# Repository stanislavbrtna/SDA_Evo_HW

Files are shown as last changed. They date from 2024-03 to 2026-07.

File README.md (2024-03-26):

# SDA Evo Hardware Sources
Evo is a second iteration of the SDA design, it improves the SDA Wonder while using a similar form-factor. Shematics will be mostly shared with the SDA Trié.
In the pcb directory are KiCad project files for the boards used in the SDA. In the case Directory there are FreeCAD files for the SDA case.
You can find more info about the SDA Project on its [project page](https://hackaday.io/project/35165-sda-the-best-new-pda) on hackaday.io.

This design is work-in-progress.

## Known Bugs
Design is not yet verified.

## Case notes

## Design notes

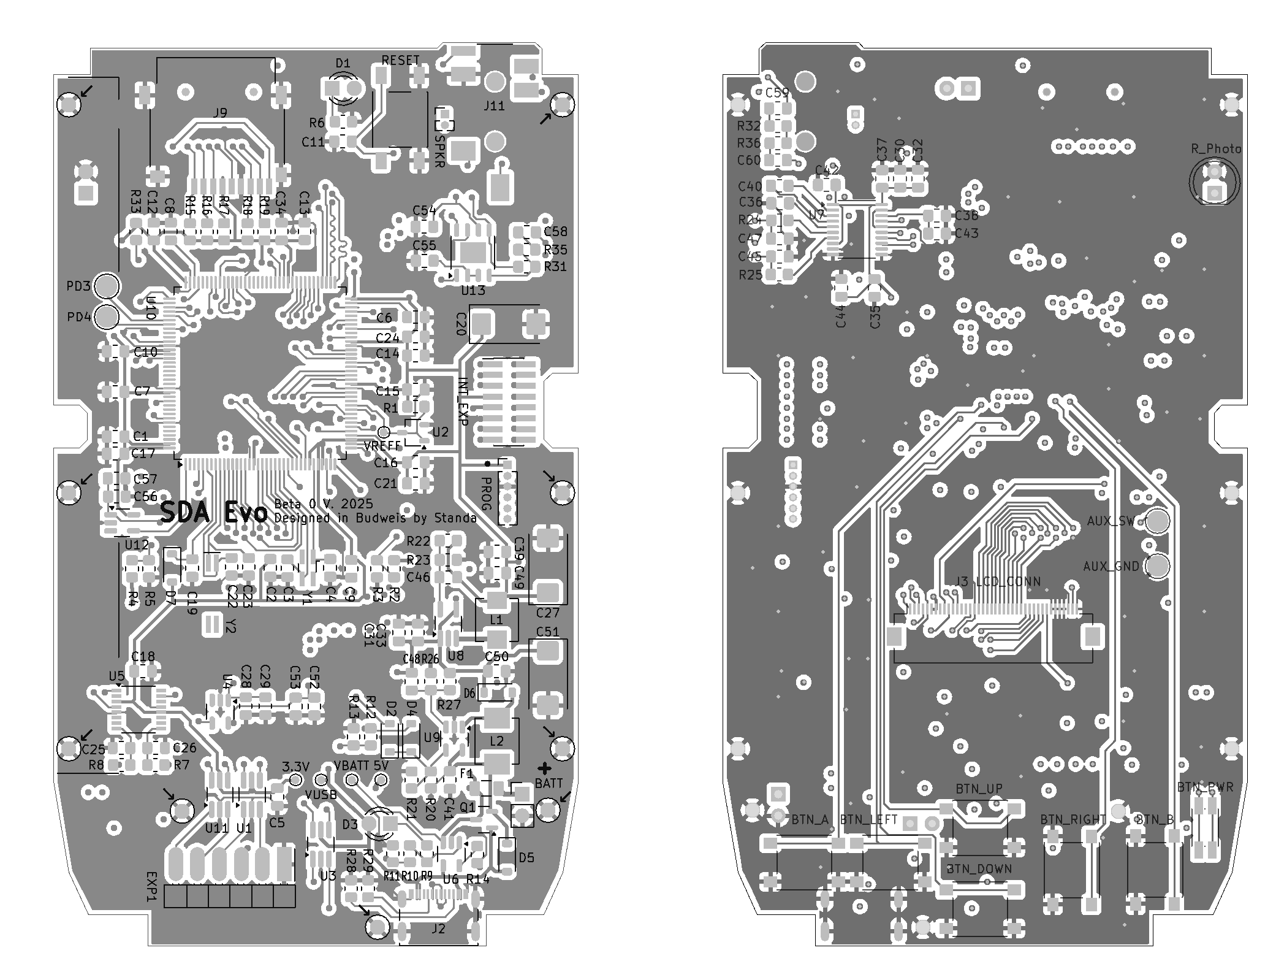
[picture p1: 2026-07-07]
Docs/Beta0/layouts.png

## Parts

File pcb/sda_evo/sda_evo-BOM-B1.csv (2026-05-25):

Reference | Value | Datasheet | Footprint | Qty | DNP
C1,C2,C5,C7,C9,C10,C11,C12,C13,C14,C15,C16,C17,C18,C28,C32,C34,C37,C43,C44,C46,C52,C54,C56 | 100n | ~ | Capacitor_SMD:C_0805_2012Metric_Pad1.18x1.45mm_HandSolder | 24
C3,C4,C22,C23 | 15p | ~ | Capacitor_SMD:C_0805_2012Metric_Pad1.18x1.45mm_HandSolder | 4
C6,C8,C19,C29,C36,C41,C57 | 2.2u | ~ | Capacitor_SMD:C_0805_2012Metric_Pad1.18x1.45mm_HandSolder | 7
C20,C27,C33,C49,C51 | 47u | ~ | Capacitor_SMD:C_0805_2012Metric_Pad1.18x1.45mm_HandSolder,Capacitor_Tantalum_SMD:CP_EIA-7343-15_Kemet-W_Pad2.25x2.55mm_HandSolder | 5
C21,C31,C39,C50,C53 | 4.7u | ~ | Capacitor_SMD:C_0805_2012Metric_Pad1.18x1.45mm_HandSolder | 5
C24,C30,C35,C38,C42 | 10u | ~ | Capacitor_SMD:C_0805_2012Metric_Pad1.18x1.45mm_HandSolder | 5
C25,C26 | 47p | ~ | Capacitor_SMD:C_0805_2012Metric_Pad1.18x1.45mm_HandSolder | 2
C40 | 22u | ~ | Capacitor_SMD:C_0805_2012Metric_Pad1.18x1.45mm_HandSolder | 1
C45,C47 | 2.2n | ~ | Capacitor_SMD:C_0805_2012Metric_Pad1.18x1.45mm_HandSolder | 2
C48 | 680p | ~ | Capacitor_SMD:C_0805_2012Metric_Pad1.18x1.45mm_HandSolder | 1
C55 | 1u | ~ | Capacitor_SMD:C_0805_2012Metric_Pad1.18x1.45mm_HandSolder | 1
C58,C59,C60 | 390n | ~ | Capacitor_SMD:C_0805_2012Metric_Pad1.18x1.45mm_HandSolder | 3
D1 | SYS_LED | ~ | LED_THT:LED_D3.0mm_FlatTop | 1
D3 | CHRG_LED | ~ | sda-parts:LED_SMD_custom | 1
D4 | BZT52-C3V3X | ~ | Diode_SMD:Nexperia_CFP3_SOD-123W | 1
D5 | S1ABF | https://www.vishay.com/docs/85748/1n4148w.pdf | Diode_SMD:D_SMB | 1
D6 | MBR0520 | http://www.mccsemi.com/up_pdf/MBR0520~MBR0580(SOD123).pdf | Diode_SMD:D_SOD-123 | 1
D7,D8,D9 | 1N5819HW-7-F | ~ | Diode_SMD:D_SOD-123 | 3
EXP1 | Conn_01x06 | ~ | sda-parts:2.54x6_flat | 1
F1 | 2A | ~ | Fuse:Fuse_1206_3216Metric | 1
H1,H2,H3,H4,H5,H6,H7,H8,H9 | Hole | ~ | sda-parts:Hole 1,6mm | 9
J1 | PROG | ~ | Connector_PinHeader_1.27mm:PinHeader_1x06_P1.27mm_Vertical | 1
J2 | USB_C_Receptacle_USB2.0 | https://www.usb.org/sites/default/files/documents/usb_type-c.zip | sda-parts:USB_C | 1
J3 | LCD_CONN | ~ | Connector_FFC-FPC:Hirose_FH12-40S-0.5SH_1x40-1MP_P0.50mm_Horizontal | 1
J4 | INT_EXP | ~ | Connector_PinHeader_1.27mm:PinHeader_2x08_P1.27mm_Vertical_SMD | 1
J5 | BATT | ~ | Connector_PinHeader_2.54mm:PinHeader_1x02_P2.54mm_Horizontal | 1
J9 | Micro_SD_Card_Det | https://www.hirose.com/product/en/download_file/key_name/DM3/category/Catalog/doc_file_id/49662/?item_id=195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 | sda-parts:SD-Connector | 1
J10 | SPKR | ~ | Connector_PinHeader_1.27mm:PinHeader_1x02_P1.27mm_Vertical | 1
J11 | AudioJack | ~ | sda-parts:3.5 Jack | 1
L1 | 4.7uH | ~ | sda-parts:HCM1A4020V2 | 1
L2 | 10uH | ~ | sda-parts:SDN0530MT100 | 1
Q1 | IRLML6302 | https://www.infineon.com/dgdl/irlml5203pbf.pdf?fileId=5546d462533600a40153566868da261d | Package_TO_SOT_SMD:SOT-23 | 1
R1,R2,R4,R10,R12,R31,R33 | 10k | ~ | Resistor_SMD:R_0805_2012Metric_Pad1.20x1.40mm_HandSolder | 7
R3,R5,R11 | 15k | ~ | Resistor_SMD:R_0805_2012Metric_Pad1.20x1.40mm_HandSolder | 3
R6 | 220 | ~ | Resistor_SMD:R_0805_2012Metric_Pad1.20x1.40mm_HandSolder | 1
R7,R8 | 27 | ~ | Resistor_SMD:R_0805_2012Metric_Pad1.20x1.40mm_HandSolder | 2
R9,R24,R25 | 470 | ~ | Resistor_SMD:R_0805_2012Metric_Pad1.20x1.40mm_HandSolder | 3
R13 | 100K | ~ | Resistor_SMD:R_0805_2012Metric_Pad1.20x1.40mm_HandSolder | 1
R14 | 1k2 1% | ~ | Resistor_SMD:R_0805_2012Metric_Pad1.20x1.40mm_HandSolder | 1
R15,R16,R17,R18,R19,R21 | 47k | ~ | Resistor_SMD:R_0805_2012Metric_Pad1.20x1.40mm_HandSolder | 6
R20,R41 | placeholder | ~ | Resistor_SMD:R_0805_2012Metric_Pad1.20x1.40mm_HandSolder | 2
R22 | 680K | ~ | Resistor_SMD:R_0805_2012Metric_Pad1.20x1.40mm_HandSolder | 1
R23 | 150K | ~ | Resistor_SMD:R_0805_2012Metric_Pad1.20x1.40mm_HandSolder | 1
R26 | 13k3 | ~ | Resistor_SMD:R_0805_2012Metric_Pad1.20x1.40mm_HandSolder | 1
R27 | 40k2 | ~ | Resistor_SMD:R_0805_2012Metric_Pad1.20x1.40mm_HandSolder | 1
R28,R29 | 5.2k | ~ | Resistor_SMD:R_0805_2012Metric_Pad1.20x1.40mm_HandSolder | 2
R30,R37 | 0 | ~ | Resistor_SMD:R_0805_2012Metric_Pad1.20x1.40mm_HandSolder | 2
R32,R35,R36 | 20k | ~ | Resistor_SMD:R_0805_2012Metric_Pad1.20x1.40mm_HandSolder | 3
R34 | R_Photo | ~ | LED_THT:LED_D5.0mm | 1
R42,R43 | 10K | ~ | Resistor_SMD:R_0805_2012Metric_Pad1.20x1.40mm_HandSolder | 2
SW1 | RESET | ~ | sda-parts:SW_SPST_RESET | 1
SW2 | BTN_A | ~ | Button_Switch_SMD:SW_SPST_PTS645 | 1
SW3 | BTN_B | ~ | Button_Switch_SMD:SW_SPST_PTS645 | 1
SW4 | BTN_UP | ~ | Button_Switch_SMD:SW_SPST_PTS645 | 1
SW5 | BTN_DOWN | ~ | Button_Switch_SMD:SW_SPST_PTS645 | 1
SW6 | BTN_LEFT | ~ | Button_Switch_SMD:SW_SPST_PTS645 | 1
SW7 | BTN_RIGHT | ~ | Button_Switch_SMD:SW_SPST_PTS645 | 1
SW8 | BTN_PWR | ~ | sda-parts:SW_Push_1P1T_NO_CK_KMR2_PWR | 1
TP1 | VREFF | ~ | TestPoint:TestPoint_Pad_D1.0mm | 1
TP2 | VUSB | ~ | TestPoint:TestPoint_Pad_D1.0mm | 1
TP3 | VBATT | ~ | TestPoint:TestPoint_Pad_D1.0mm | 1
TP4,TP11 | 3.3V | ~ | TestPoint:TestPoint_Pad_D1.0mm,TestPoint:TestPoint_Pad_D2.5mm | 2
TP5 | 5V | ~ | TestPoint:TestPoint_Pad_D1.0mm | 1
TP6 | AUX_SW | ~ | TestPoint:TestPoint_Pad_D2.5mm | 1
TP7 | AUX_GND | ~ | TestPoint:TestPoint_Pad_D2.5mm | 1
TP8 | PD3 | ~ | TestPoint:TestPoint_Pad_D2.5mm | 1
TP9 | PD4 | ~ | TestPoint:TestPoint_Pad_D2.5mm | 1
TP10 | VCAP | ~ | TestPoint:TestPoint_Pad_D1.0mm | 1
TP12 | GND | ~ | TestPoint:TestPoint_Pad_D2.5mm | 1
U1,U3,U11 | USBLC6 |  | Package_TO_SOT_SMD:TSOT-23-6_HandSoldering | 3
U2 | TLV431 |  | Package_TO_SOT_SMD:TSOT-23 | 1
U4,U12 | AP22802AW5-7 | https://www.diodes.com/assets/Datasheets/AP22804_14.pdf | Package_TO_SOT_SMD:SOT-23-5_HandSoldering | 2
U5 | FT230XS | https://www.ftdichip.com/Support/Documents/DataSheets/ICs/DS_FT230X.pdf | Package_SO:SSOP-16_3.9x4.9mm_P0.635mm | 1
U7 | PCM5102 | http://www.ti.com/lit/ds/symlink/pcm5102.pdf | Package_SO:TSSOP-20_4.4x6.5mm_P0.65mm | 1
U8 | NCP1529 |  | Package_TO_SOT_SMD:SOT-23-5_HandSoldering | 1
U9 | LMR62014XMF | http://www.ti.com/lit/ds/symlink/lmr62014.pdf | Package_TO_SOT_SMD:SOT-23-5_HandSoldering | 1
U10 | STM32H743ZITx | http://www.st.com/st-web-ui/static/active/en/resource/technical/document/datasheet/DM00387108.pdf | Package_QFP:LQFP-144_20x20mm_P0.5mm | 1
U13 | LM4861 |  | Package_SO:HSOP-8-1EP_3.9x4.9mm_P1.27mm_EP2.41x3.1mm | 1
U14 | STC4054 |  | Package_TO_SOT_SMD:SOT-23-5_HandSoldering | 1
Y1 | 16Mhz | ~ | sda-parts:SMDXT224 | 1
Y2 | 32.768 | ~ | sda-parts:Crystal_SMD_6.7x1.5mm_HandSoldering | 1

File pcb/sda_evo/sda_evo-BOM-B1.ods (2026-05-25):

In Stock | Order | Reference | Value | Qty | Datasheet | Footprint | DNP
 |  | C1,C2,C5,C7,C9,C10,C11,C12,C13,C14,C15,C16,C17, C18,C28,C32,C34,C37,C43,C44,C46,C52,C54,C56 | 100n | 24 | ~ | Capacitor_SMD:C_0805_2012Metric_Pad1.18x1.45mm_HandSolder
 | 100 | C3,C4,C22,C23 | 15p | 4 | ~ | Capacitor_SMD:C_0805_2012Metric_Pad1.18x1.45mm_HandSolder
 |  | C6,C8,C19,C29,C36,C41,C57 | 2.2u | 7 | ~ | Capacitor_SMD:C_0805_2012Metric_Pad1.18x1.45mm_HandSolder
Jen 2 tant. | 10 | C20,C27,C33,C49,C51 | 47u | 5 | ~ | Capacitor_SMD:C_0805_2012Metric_Pad1.18x1.45mm_HandSolder,Capacitor_Tantalum_SMD:CP_EIA-7343-15_Kemet-W_Pad2.25x2.55mm_HandSolder
 |  | C21,C31,C39,C50,C53 | 4.7u | 5 | ~ | Capacitor_SMD:C_0805_2012Metric_Pad1.18x1.45mm_HandSolder
 |  | C24,C30,C35,C38,C42 | 10u | 5 | ~ | Capacitor_SMD:C_0805_2012Metric_Pad1.18x1.45mm_HandSolder
 |  | C25,C26 | 47p | 2 | ~ | Capacitor_SMD:C_0805_2012Metric_Pad1.18x1.45mm_HandSolder
 |  | C40 | 22u | 1 | ~ | Capacitor_SMD:C_0805_2012Metric_Pad1.18x1.45mm_HandSolder
 |  | C45,C47 | 2.2n | 2 | ~ | Capacitor_SMD:C_0805_2012Metric_Pad1.18x1.45mm_HandSolder
 |  | C48 | 680p | 1 | ~ | Capacitor_SMD:C_0805_2012Metric_Pad1.18x1.45mm_HandSolder
 |  | C55 | 1u | 1 | ~ | Capacitor_SMD:C_0805_2012Metric_Pad1.18x1.45mm_HandSolder
 |  | C58,C59,C60 | 390n | 3 | ~ | Capacitor_SMD:C_0805_2012Metric_Pad1.18x1.45mm_HandSolder
 |  | D1 | SYS_LED | 1 | ~ | LED_THT:LED_D3.0mm_FlatTop
 |  | D3 | CHRG_LED | 1 | ~ | sda-parts:LED_SMD_custom
 | 10 | D4 | BZT52-C3V3X | 1 | ~ | Diode_SMD:Nexperia_CFP3_SOD-123W
 | 25 | D5 | S1ABF | 1 | https://www.vishay.com/docs/85748/1n4148w.pdf | Diode_SMD:D_SMB
 |  | D6 | MBR0520 | 1 | http://www.mccsemi.com/up_pdf/MBR0520~MBR0580(SOD123).pdf | Diode_SMD:D_SOD-123
jen 2ks | 10 | D7,D8,D9 | 1N5819HW-7-F | 3 | ~ | Diode_SMD:D_SOD-123
 |  | EXP1 | Conn_01x06 | 1 | ~ | sda-parts:2.54x6_flat
 |  | F1 | 2A | 1 | ~ | Fuse:Fuse_1206_3216Metric
 |  | J1 | PROG | 1 | ~ | Connector_PinHeader_1.27mm:PinHeader_1x06_P1.27mm_Vertical
 | 10 | J2 | USB_C_Receptacle_USB2.0 | 1 | https://www.usb.org/sites/default/files/documents/usb_type-c.zip | sda-parts:USB_C
4 |  | J3 | LCD_CONN | 1 | ~ | Connector_FFC-FPC:Hirose_FH12-40S-0.5SH_1x40-1MP_P0.50mm_Horizontal
 |  | J4 | INT_EXP | 1 | ~ | Connector_PinHeader_1.27mm:PinHeader_2x08_P1.27mm_Vertical_SMD
 |  | J5 | BATT | 1 | ~ | Connector_PinHeader_2.54mm:PinHeader_1x02_P2.54mm_Horizontal
 | 2 | J9 | Micro_SD_Card_Det | 1 | https://www.hirose.com/product/en/download_file/key_name/DM3/category/Catalog/doc_file_id/49662/?item_id=195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 | sda-parts:SD-Connector
1ks |  | J11 | AudioJack | 1 | ~ | sda-parts:3.5 Jack
 |  | L1 | 4.7uH | 1 | ~ | sda-parts:HCM1A4020V2
1 ks? |  | L2 | 10uH | 1 | ~ | sda-parts:SDN0530MT100
 |  | Q1 | IRLML6302 | 1 | https://www.infineon.com/dgdl/irlml5203pbf.pdf?fileId=5546d462533600a40153566868da261d | Package_TO_SOT_SMD:SOT-23
 |  | R1,R2,R4,R10,R12,R31,R33 | 10k | 7 | ~ | Resistor_SMD:R_0805_2012Metric_Pad1.20x1.40mm_HandSolder
 |  | R3,R5,R11 | 15k | 3 | ~ | Resistor_SMD:R_0805_2012Metric_Pad1.20x1.40mm_HandSolder
 |  | R6 | 220 | 1 | ~ | Resistor_SMD:R_0805_2012Metric_Pad1.20x1.40mm_HandSolder
 |  | R7,R8 | 27 | 2 | ~ | Resistor_SMD:R_0805_2012Metric_Pad1.20x1.40mm_HandSolder
 |  | R9,R24,R25 | 470 | 3 | ~ | Resistor_SMD:R_0805_2012Metric_Pad1.20x1.40mm_HandSolder
 | 100 | R13 | 100K | 1 | ~ | Resistor_SMD:R_0805_2012Metric_Pad1.20x1.40mm_HandSolder
 |  | R14 | 1k2 1% | 1 | ~ | Resistor_SMD:R_0805_2012Metric_Pad1.20x1.40mm_HandSolder
 |  | R15,R16,R17,R18,R19,R21 | 47k | 6 | ~ | Resistor_SMD:R_0805_2012Metric_Pad1.20x1.40mm_HandSolder
 |  | R20,R41 | placeholder | 2 | ~ | Resistor_SMD:R_0805_2012Metric_Pad1.20x1.40mm_HandSolder
 |  | R22 | 680K | 1 | ~ | Resistor_SMD:R_0805_2012Metric_Pad1.20x1.40mm_HandSolder
 |  | R23 | 150K | 1 | ~ | Resistor_SMD:R_0805_2012Metric_Pad1.20x1.40mm_HandSolder
 |  | R26 | 13k3 | 1 | ~ | Resistor_SMD:R_0805_2012Metric_Pad1.20x1.40mm_HandSolder
 |  | R27 | 40k2 | 1 | ~ | Resistor_SMD:R_0805_2012Metric_Pad1.20x1.40mm_HandSolder
 |  | R28,R29 | 5.2k | 2 | ~ | Resistor_SMD:R_0805_2012Metric_Pad1.20x1.40mm_HandSolder
 |  | R30,R37 | 0 | 2 | ~ | Resistor_SMD:R_0805_2012Metric_Pad1.20x1.40mm_HandSolder
 |  | R32,R35,R36 | 20k | 3 | ~ | Resistor_SMD:R_0805_2012Metric_Pad1.20x1.40mm_HandSolder
 |  | R34 | R_Photo | 1 | ~ | LED_THT:LED_D5.0mm
 |  | R42,R43 | 10K | 2 | ~ | Resistor_SMD:R_0805_2012Metric_Pad1.20x1.40mm_HandSolder
 |  | SW1 | BTN_RESET | 1 | ~ | sda-parts:SW_SPST_RESET
 |  | SW2 | BTN | 6 | ~ | Button_Switch_SMD:SW_SPST_PTS645
 |  | SW8 | BTN_PWR | 1 | ~ | sda-parts:SW_Push_1P1T_NO_CK_KMR2_PWR
 |  | U1,U3,U11 | USBLC6 | 3 |  | Package_TO_SOT_SMD:TSOT-23-6_HandSoldering
 |  | U2 | TLV431 | 1 |  | Package_TO_SOT_SMD:TSOT-23
 | 25 | U4,U12 | AP22802AW5-7 | 2 | https://www.diodes.com/assets/Datasheets/AP22804_14.pdf | Package_TO_SOT_SMD:SOT-23-5_HandSoldering
 |  | U5 | FT230XS | 1 | https://www.ftdichip.com/Support/Documents/DataSheets/ICs/DS_FT230X.pdf | Package_SO:SSOP-16_3.9x4.9mm_P0.635mm
1ks |  | U7 | PCM5102 | 1 | http://www.ti.com/lit/ds/symlink/pcm5102.pdf | Package_SO:TSSOP-20_4.4x6.5mm_P0.65mm
 |  | U8 | NCP1529 | 1 |  | Package_TO_SOT_SMD:SOT-23-5_HandSoldering
 |  | U9 | LMR62014XMF | 1 | http://www.ti.com/lit/ds/symlink/lmr62014.pdf | Package_TO_SOT_SMD:SOT-23-5_HandSoldering
2ks |  | U10 | STM32H743ZITx | 1 | http://www.st.com/st-web-ui/static/active/en/resource/technical/document/datasheet/DM00387108.pdf | Package_QFP:LQFP-144_20x20mm_P0.5mm
 |  | U13 | LM4861 | 1 |  | Package_SO:HSOP-8-1EP_3.9x4.9mm_P1.27mm_EP2.41x3.1mm
 | 3 | U14 | STC4054 | 1 |  | Package_TO_SOT_SMD:SOT-23-5_HandSoldering
1ks | 1ks skladem | Y1 | 16Mhz | 1 | ~ | sda-parts:SMDXT224
 |  | Y2 | 32.768 | 1 | ~ | sda-parts:Crystal_SMD_6.7x1.5mm_HandSoldering
 |  | Speaker |  | 1
 |  | Vibro |  | 1
1ks |  | Batt |  | 1

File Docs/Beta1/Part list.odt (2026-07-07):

SDA EVO B1

Reference | Value
C1,C2,C5,C7,C9,C10,C11,C12,C13,C14,C15,C16,C17, C18,C28,C32,C34,C37,C43,C44,C46,C52,C54,C56 | 100n
C3,C4,C22,C23 | 15p
C6,C8,C19,C29,C36,C41,C57 | 2.2u
C20,C27,C33,C49,C51 | 47u
C21,C31,C39,C50,C53 | 4.7u
C24,C30,C35,C38,C42 | 10u
C25,C26 | 47p
C40 | 22u
C45,C47 | 2.2n
C48 | 680p
C55 | 1u
C58,C59,C60 | 390n
D1 | SYS_LED
D3 | CHRG_LED
D4 | BZT52-C3V3X
D5 | S1ABF
D6 | MBR0520
D7,D8,D9 | 1N5819HW-7-F
EXP1 | Conn_01x06
F1 | 2A
L1 | 4.7uH
L2 | 10uH
Q1 | IRLML6302
R1,R2,R4,R10,R12,R31,R33 | 10k
R3,R5,R11 | 15k
R6 | 220
R7,R8 | 27
R9,R24,R25 | 470
R13 | 100K
R14 | 1k2 1%
R15,R16,R17,R18,R19,R21 | 47k
R20,R41 | placeholder
R22 | 680K
R23 | 150K
R26 | 13k3
R27 | 40k2
R28,R29 | 5.2k
R30,R37 | 0
R32,R35,R36 | 20k
R34 | R_Photo
R42,R43 | 10K
U1,U3,U11 | USBLC6
U2 | TLV431
U4,U12 | AP22802AW5-7
U5 | FT230XS
U7 | PCM5102
U8 | NCP1529
U9 | LMR62014XMF
U10 | STM32H743ZITx
U13 | LM4861
U14 | STC4054
Y1 | 16Mhz
Y2 | 32.768

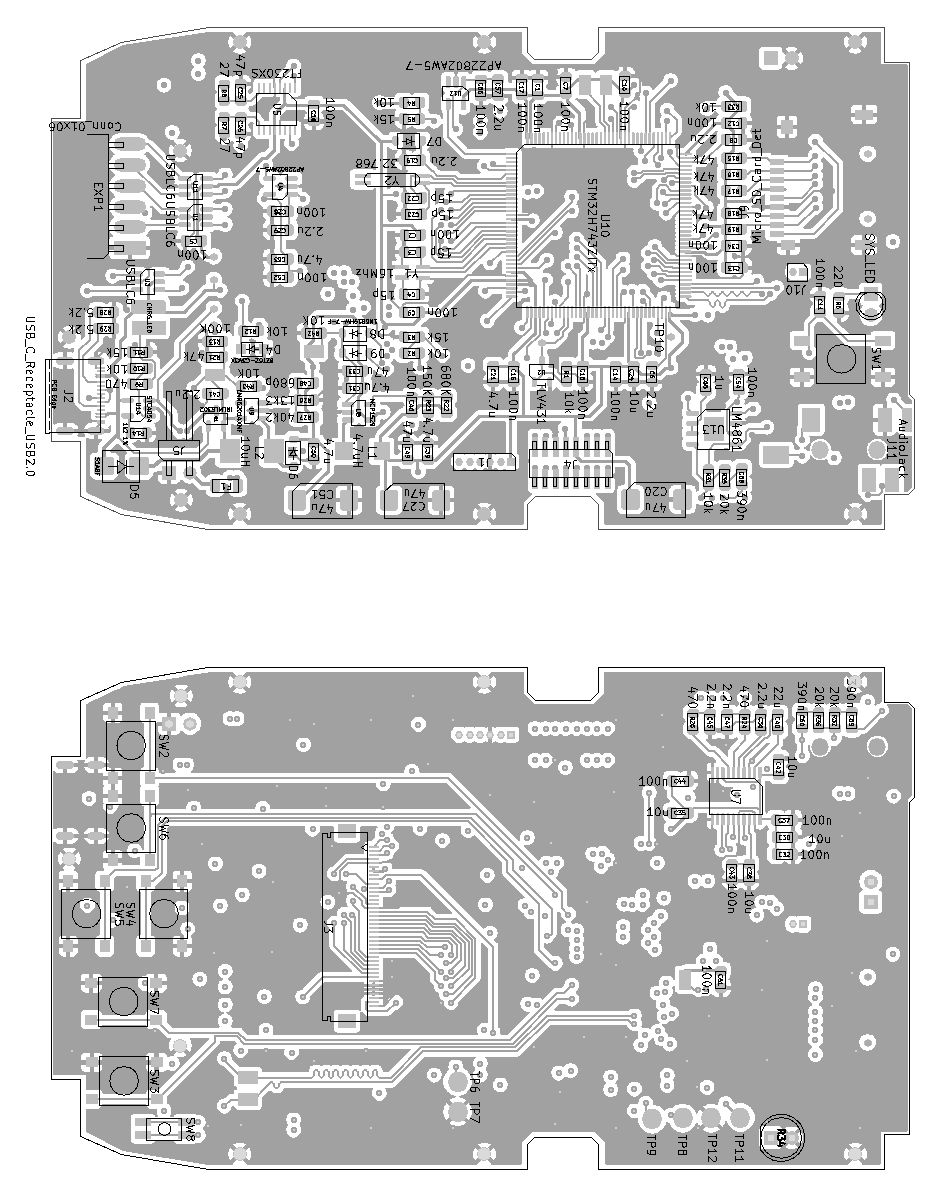
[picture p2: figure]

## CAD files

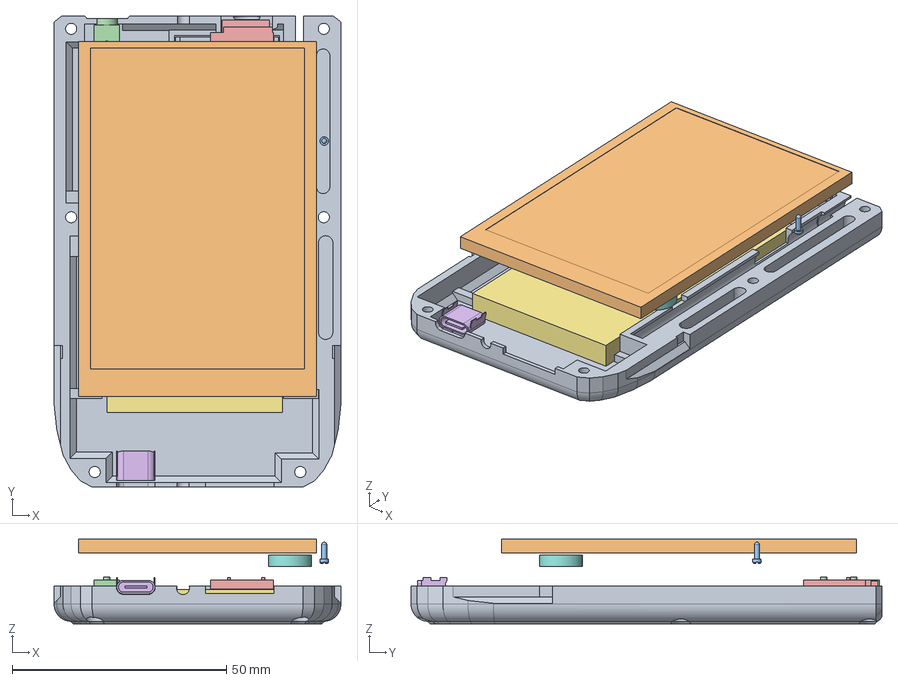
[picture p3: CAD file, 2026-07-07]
case/SDA_Evo.fcstd
67.0 x 110.0 x 19.8 mm
Back-body
precise-lcd
screw-mock
jack-mock
SD_Mock
USB-C
Batt 1,8Ah
vibro
Spkr2

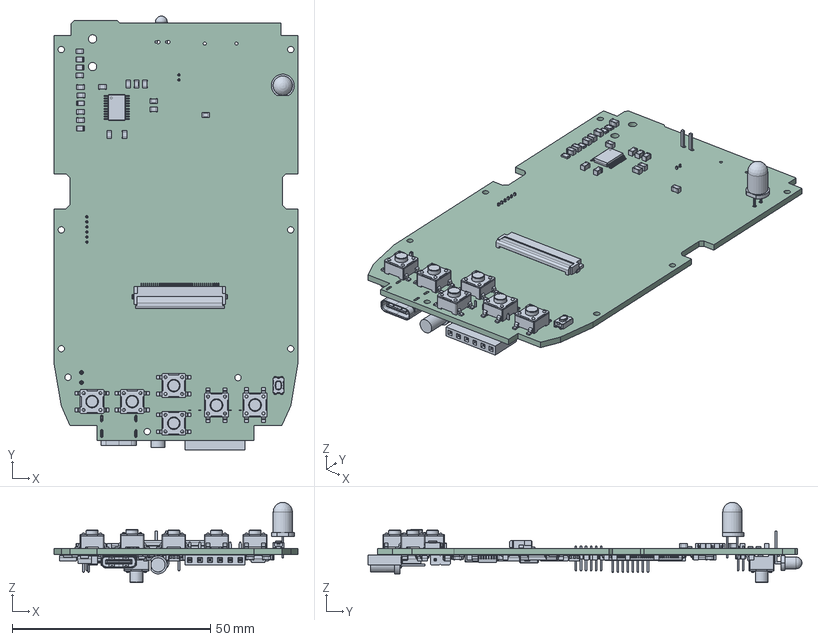
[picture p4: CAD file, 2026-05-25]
pcb/sda_evo/sda_evo.step
61.5 x 109.5 x 20.3 mm
C_0805_2012Metric x 58
SW_SPST_PTS647Sx38 x 6
R_0805_2012Metric x 35
lock
pins
LED_D5.0mm
SW_Push_1P1T_NO_CK_KMR2
TSSOP-20_4.4x6.5mm_P0.65mm
TSOT-23
D_SOD-123 x 4
LED_D3.0mm_FlatTop
USB_C_Receptacle_GCT_USB4105-xx-A_16P_TopMnt_Horizontal
SOT-23-6 x 3
Fuse_1206_3216Metric
SW_SPST_PTS647Sx50
SOT-23
L_APV_ANR3010
TQFP-144_16x16mm_P0.4mm
SOT-23-5 x 5
CP_EIA-7343-15_Kemet-W x 3
PinHeader_1x06_P1.27mm_Vertical
D_SMB
Crystal_SMD_2520-4Pin_2.5x2.0mm
PinHeader_1x02_P1.27mm_Vertical
PinHeader_1x02_P2.54mm_Horizontal
PinHeader_2x08_P1.27mm_Vertical_SMD
PinSocket_1x06_P2.54mm_Horizontal
HSOP-8-1EP_3.9x4.9mm_P1.27mm_EP2.41x3.1mm
LED_D3.0mm_Horizontal_O1.27mm_Z6.0mm
L_Abracon_ASPI-0425
SSOP-16_3.9x4.9mm_P0.635mm
Crystal_SMD_SeikoEpson_MA505-2Pin_12.7x5.1mm
sda_evo 1.137.1
sda_evo_PCB

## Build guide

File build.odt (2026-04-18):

Reference | Value
C1,C2,C5,C7,C9,C10,C11,C12,C13,C14,C15,C16,C17,C18,C28,C32,C34,C37,C43,C44,C46,C52,C54,C56 | 100n
C3,C4,C22,C23 | 15p
C6,C8,C19,C29,C36,C41,C57 | 2.2u
C20,C27,C33,C49,C51 | 47u
| 47u – tantal
C21,C31,C39,C50,C53 | 4.7u
C24,C30,C35,C38,C42 | 10u
C25,C26 | 47p
C40 | 22u
C45,C47 | 2.2n
C48 | 680p ?
C55 | 1u
C58,C59,C60 | 390n
D1 | SYS_LED
D2,D4,D7 | 1N5819HW-7-F
D3 | CHRG_LED
D5 | 1N4148W
D6 | MBR0520
EXP1 | Conn_01x06
F1 | 2A
J1 | PROG
J2 | USB_C_Receptacle_USB2.0
J3 | LCD_CONN
J4 | INT_EXP
J5 | BATT
J9 | Micro_SD_Card_Det
J10 | SPKR
J11 | AudioJack
L1 | 4.7uH
L2 | 10uH
Q1 | IRLML6302
R1,R2,R4,R10,R12,R33 | 10k
R3,R5,R11 | 15k
R6 | 220
R7,R8 | 27
R9,R24,R25 | 470
R13 | 19K
R14 | 2k
R15,R16,R17,R18,R19,R21 | 47k
R20 | placeholder
R22 | 680K
R23 | 150K
R26 | 13k3
R27 | 40k2
R28,R29 | 5.2k
R31,R32,R35,R36 | 20k
R34 | R_Photo
SW1 | RESET
SW2 | BTN_A
SW3 | BTN_B
SW4 | BTN_UP
SW5 | BTN_DOWN
SW6 | BTN_LEFT
SW7 | BTN_RIGHT
SW8 | BTN_PWR
U1,U3,U11 | USBLC6
U2 | TLV431
U4,U12 | AP22802AW5-7
U5 | FT230XS
U6 | MCP73831-2-OT
U7 | PCM5102
U8 | NCP1529
U9 | LMR62014XMF
U10 | STM32H743ZITx
U13 | LM4861
Y1 | 16Mhz
Y2 | 32.768
Vibe | DF-FITO774

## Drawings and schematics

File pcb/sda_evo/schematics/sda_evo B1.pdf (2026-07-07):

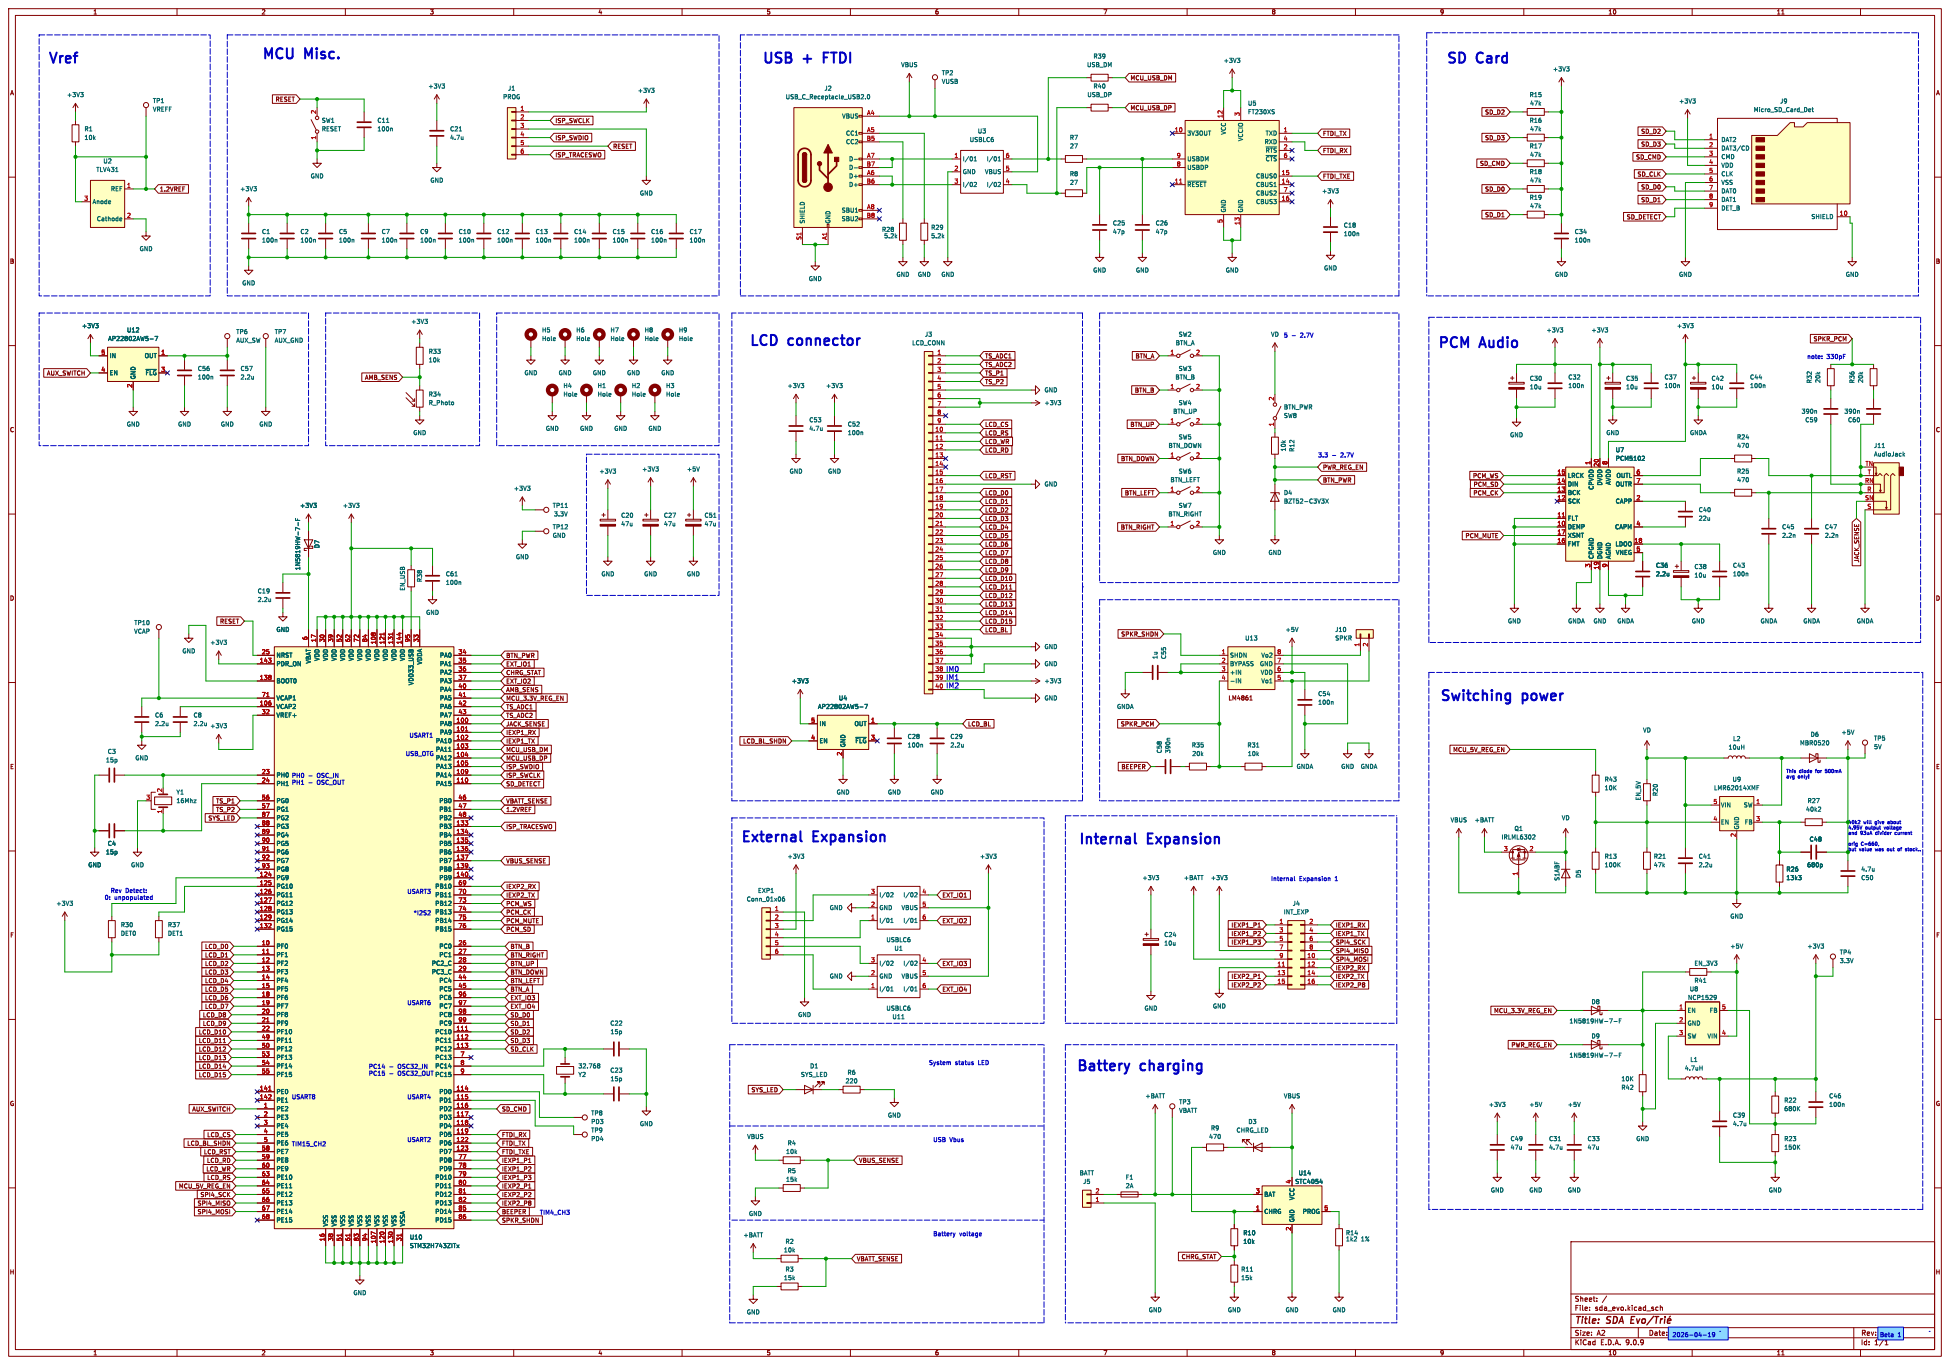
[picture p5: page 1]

6 VDD 17 VDD 30 VSS 16 VDD 39 VSS 38 VDD 52 VSS 51 VDD 62 VSS 61 VDD 72 VSS 83 VDD 84 VSS 94 VDD 108 VSS 107 VDD 121 VSS 120 VDD 131 VSS 130 VDD 144 VSSA 31 VDD33_USB 95 VDDA 33 PA0 34 PA1 35 PA2 36 PA3 37 PA4 40 PA5 41 PA6 42 PA7 43 PA8 100 PA9 101 PA10 102 PA11 103 PA12 104 PA13 105 PA14 109 PA15 110 PB0 46 PB1 47 PB2 48 PB3 133 PB4 134 PB5 135 PB6 136 PB7 137 PB8 139 PB9 140 PB10 69 PB11 70 PB12 73 PB13 74 PB14 75 PB15 76 PC0 26 PC1 27 PC2_C 28 PC3_C 29 PC4 44 PC5 45 PC6 96 PC7 97 PC8 98 PC9 99 PC10 111 PC11 112 PC12 113 PC13 7 PC14 8 PC15 9 PD0 114 PD1 115 PD2 116 PD3 117 PD4 118 PD5 119 PD6 122 PD7 123 PD8 77 PD9 78 PD10 79 PD11 80 PD12 81 PD13 82 PD14 85 PD15 86 D7 1N5819HW-7-F +3V3 GND

6 VDD 17 VDD 30 VSS 16 VDD 39 VSS 38 VDD 52 VSS 51 VDD 62 VSS 61 VDD 72 VSS 83 VDD 84 VSS 94 VDD 108 VSS 107 VDD 121 VSS 120 VDD 131 VSS 130 VDD 144 VSSA 31 VDD33_USB 95 VDDA 33 PA0 34 PA1 35 PA2 36 PA3 37 PA4 40 PA5 41 PA6 42 PA7 43 PA8 100 PA9 101 PA10 102 PA11 103 PA12 104 PA13 105 PA14 109 PA15 110 PB0 46 PB1 47 PB2 48 PB3 133 PB4 134 PB5 135 PB6 136 PB7 137 PB8 139 PB9 140 PB10 69 PB11 70 PB12 73 PB13 74 PB14 75 PB15 76 PC0 26 PC1 27 PC2_C 28 PC3_C 29 PC4 44 PC5 45 PC6 96 PC7 97 PC8 98 PC9 99 PC10 111 PC11 112 PC12 113 PC13 7 PC14 8 PC15 9 PD0 114 PD1 115 PD2 116 PD3 117 PD4 118 PD5 119 PD6 122 PD7 123 PD8 77 PD9 78 PD10 79 PD11 80 PD12 81 PD13 82 PD14 85 PD15 86 U10 STM32H743ZITx

40k2 will give about 4.95V output voltage

and 93uA divider current orig C=660, but value was out of stock.. Rev Detect: 0: unpopulated
4 U8 NCP1529 R41 EN_3V3 C4
4.7u GND

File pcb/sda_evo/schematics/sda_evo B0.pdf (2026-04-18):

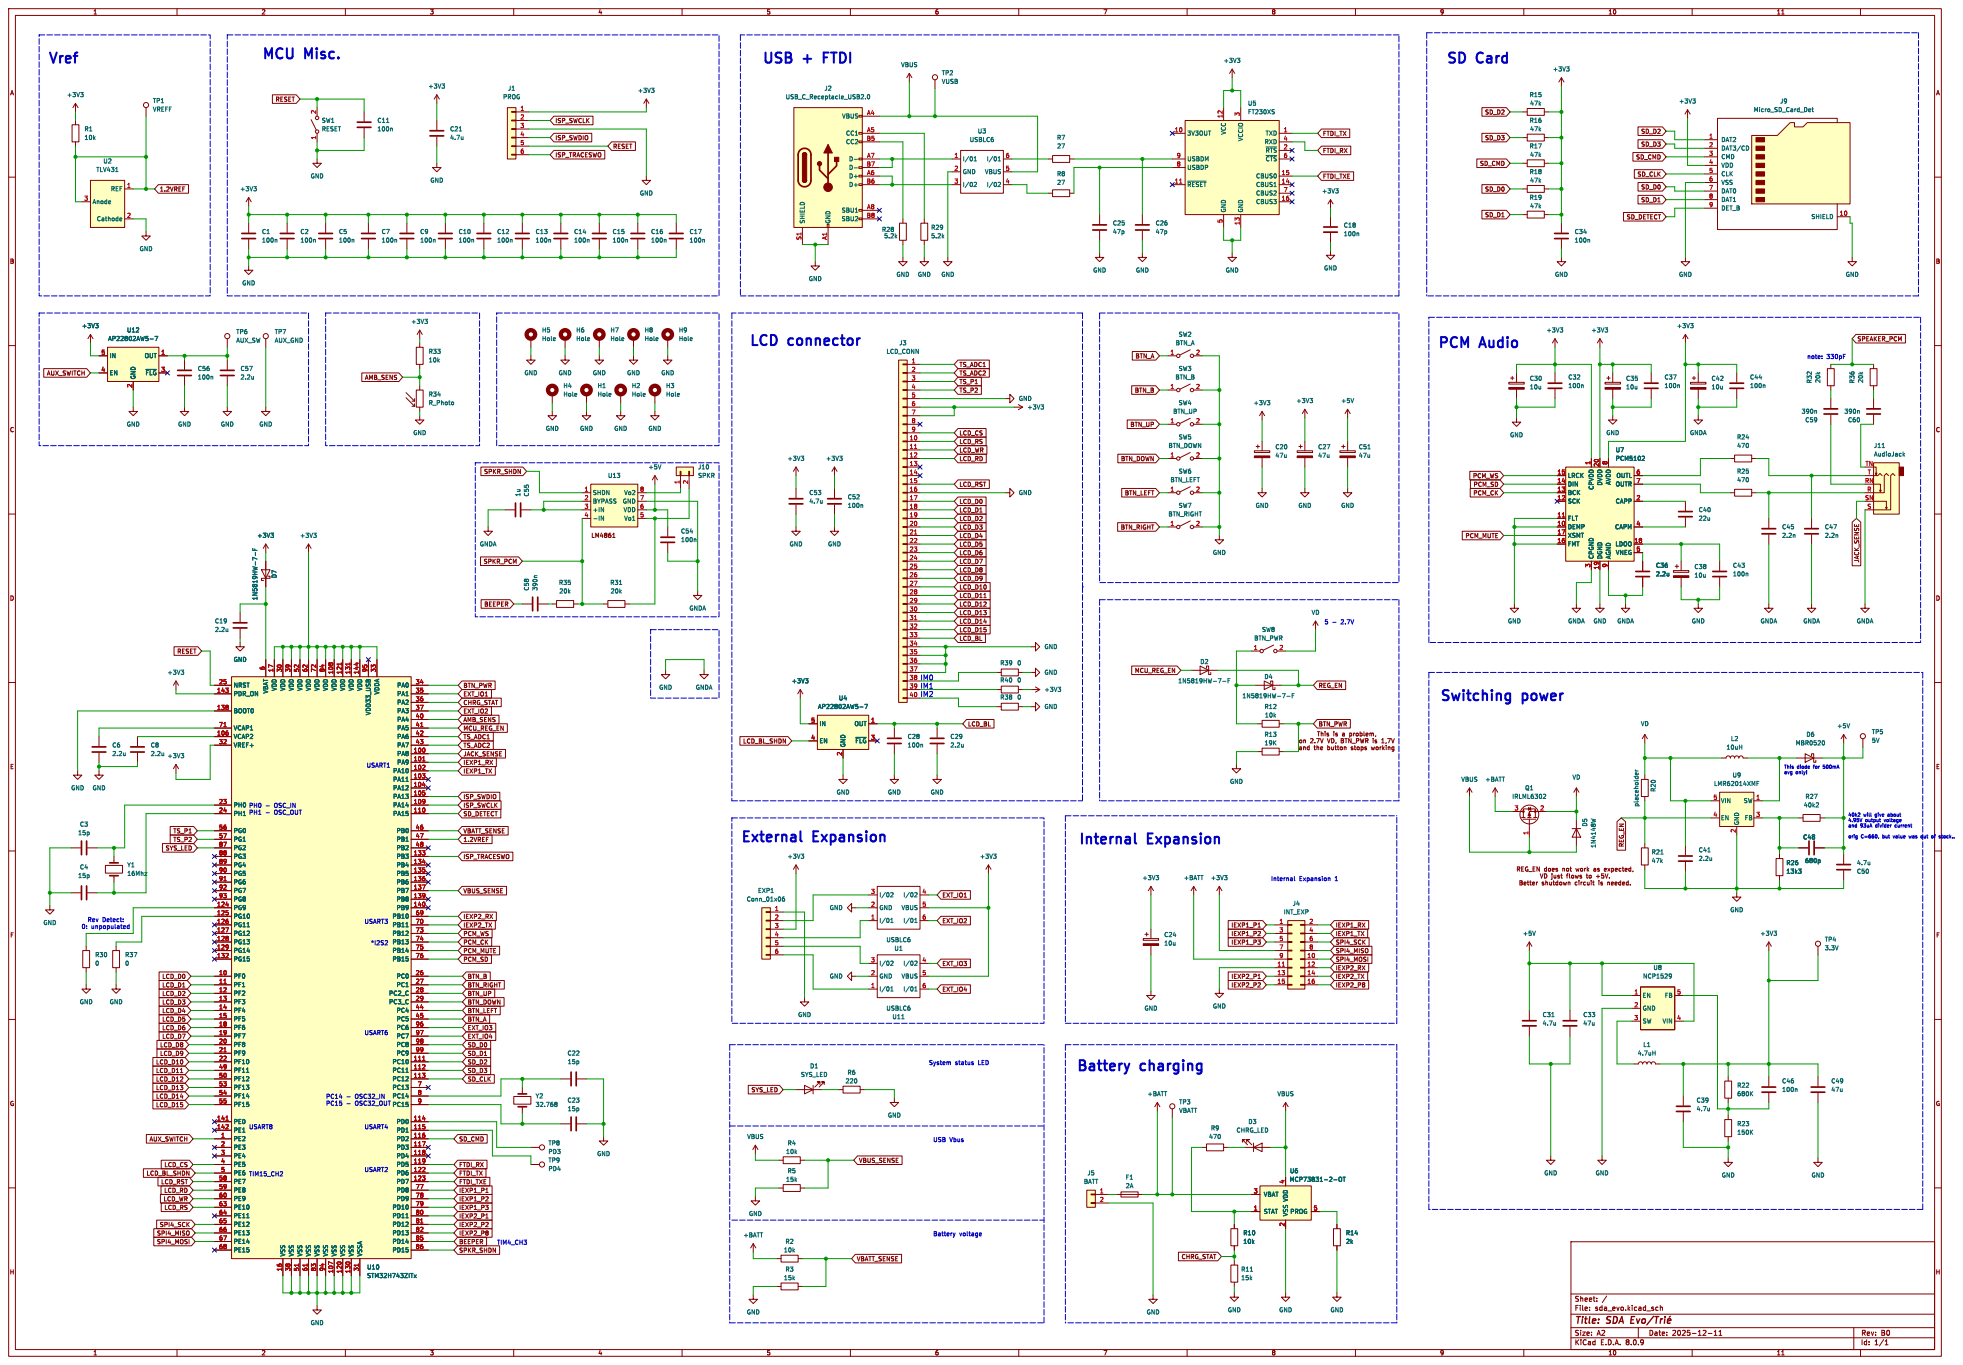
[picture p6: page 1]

GND GND

BTN_PWR
This is a problem, on 2.7V VD, BTN_PWR is 1,7V

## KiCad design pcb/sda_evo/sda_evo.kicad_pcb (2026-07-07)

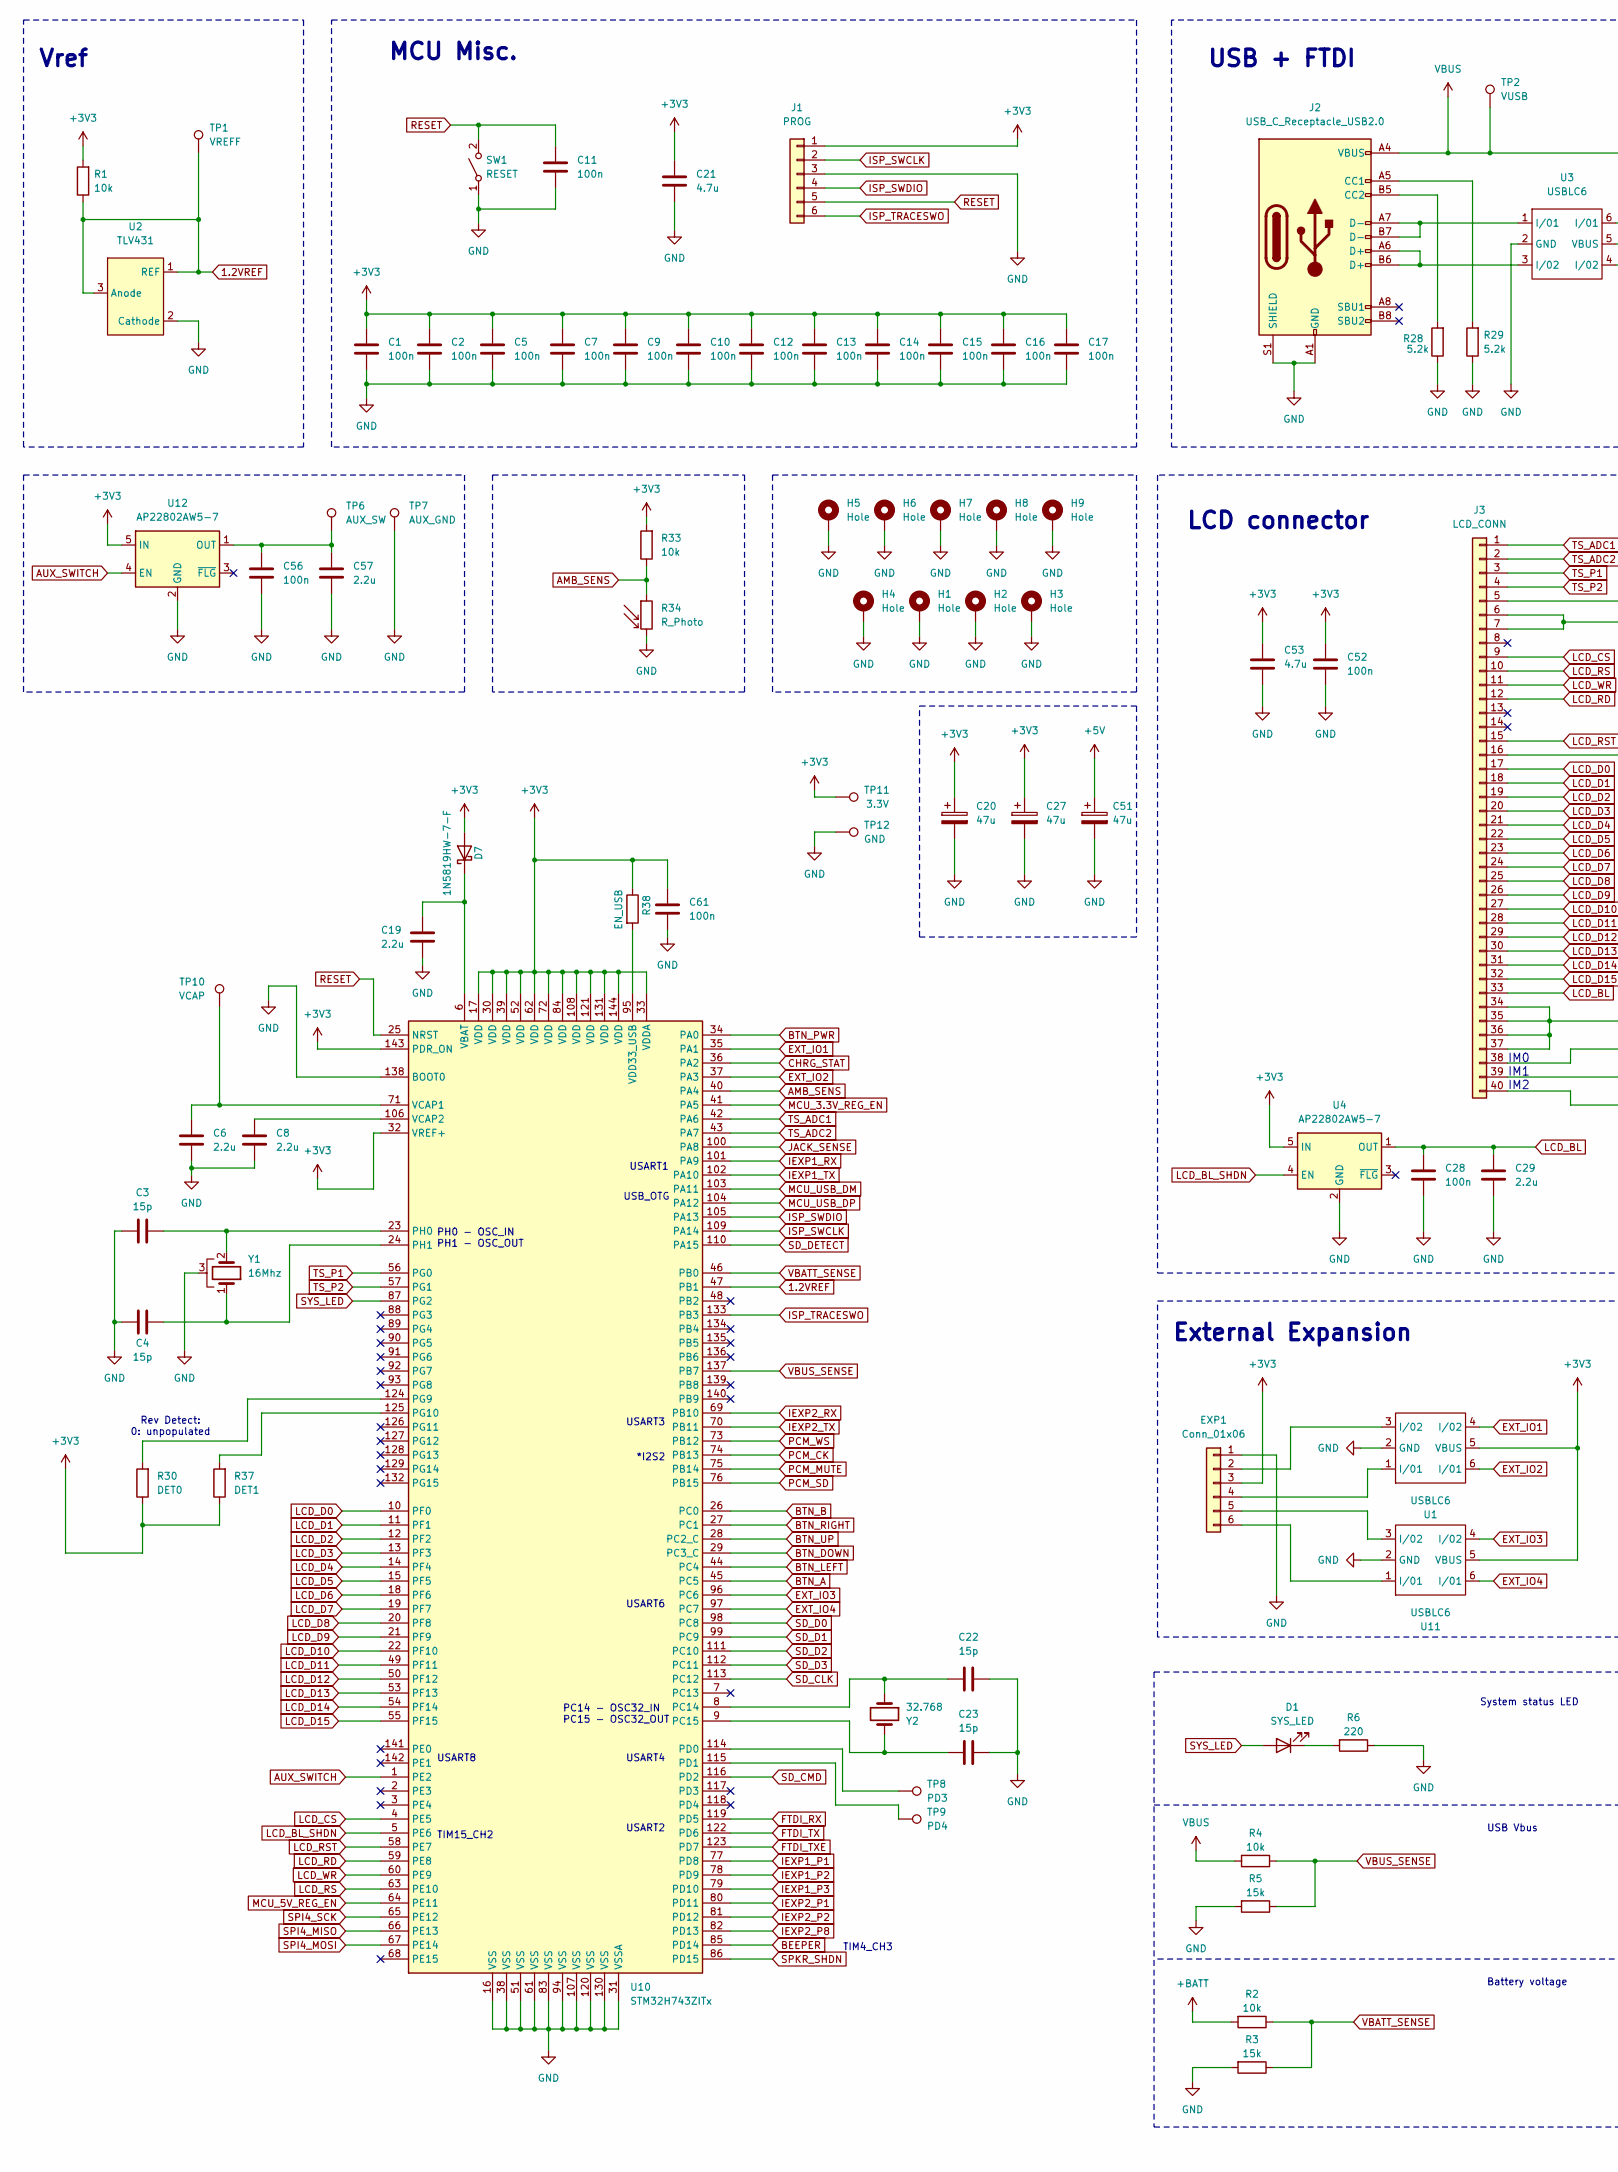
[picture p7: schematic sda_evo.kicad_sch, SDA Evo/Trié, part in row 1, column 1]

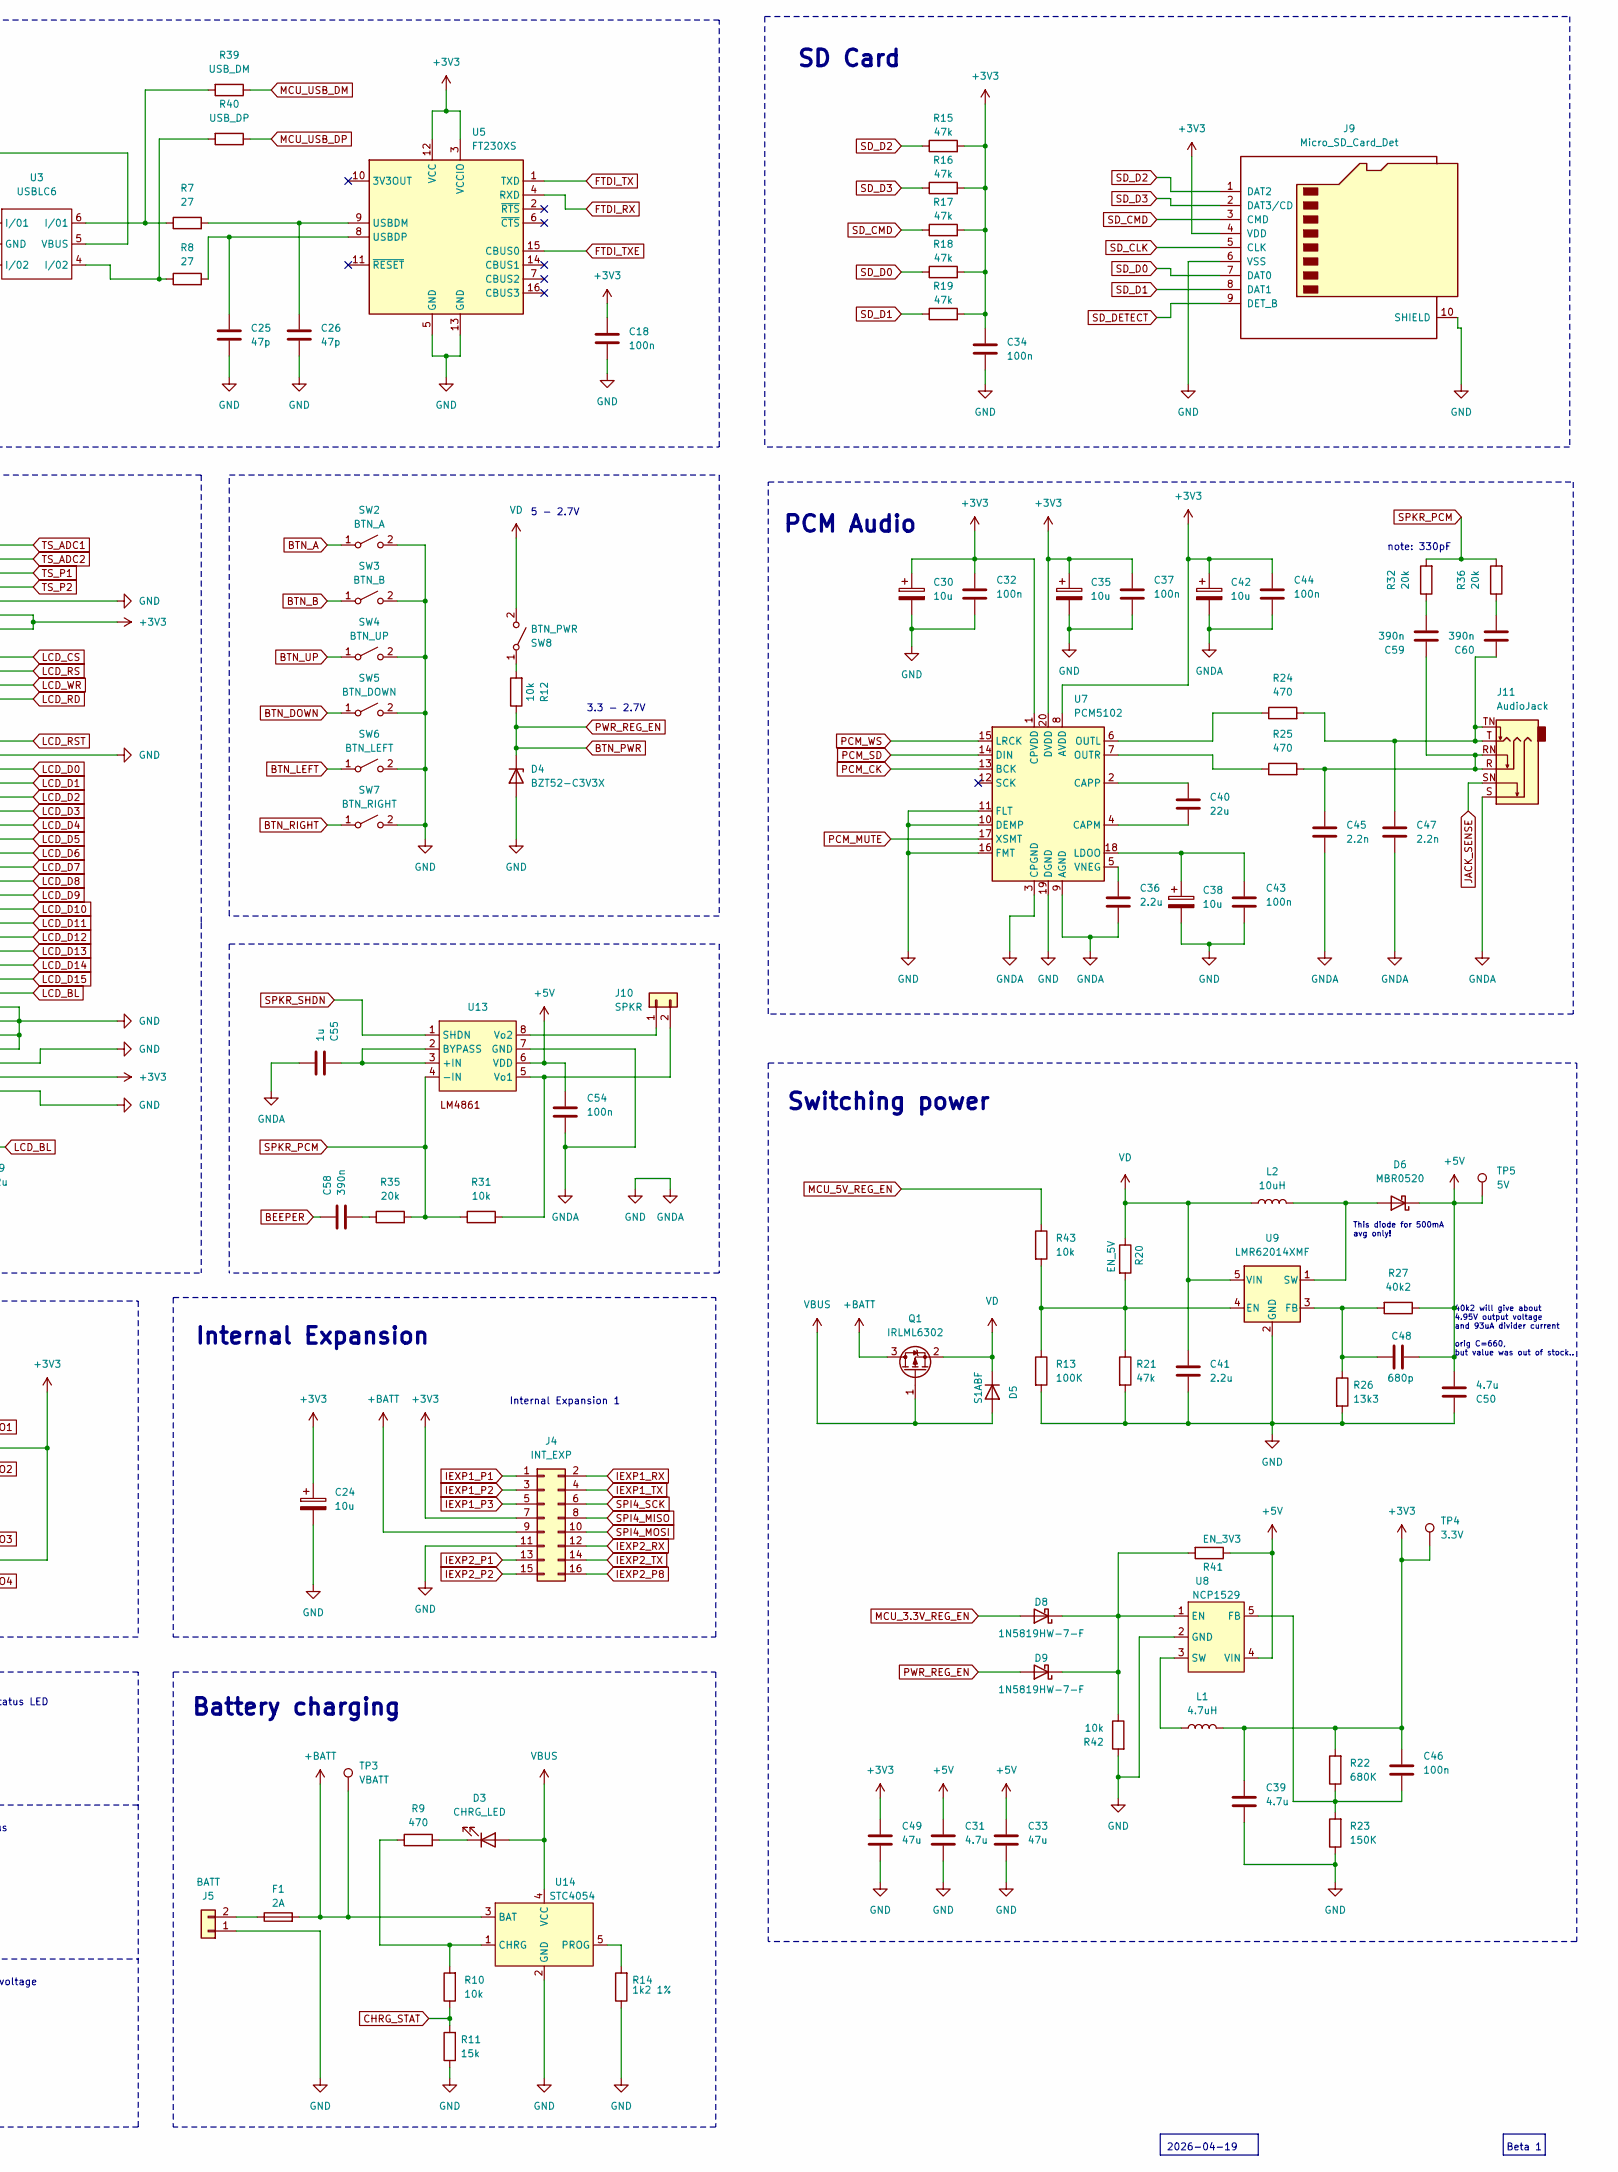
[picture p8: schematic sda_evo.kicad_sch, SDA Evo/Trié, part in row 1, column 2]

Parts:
C1, C2, C5, C7, C9, C10, C11, C12, C13, C14, C15, C16, C17, C18, C28, C32, C34, C37, C43, C44, C46, C52, C54, C56, C61: 100n; C_0805_2012Metric_Pad1.18x1.45mm_HandSolder
C3, C4, C22, C23: 15p; C_0805_2012Metric_Pad1.18x1.45mm_HandSolder
C6, C8, C19, C29, C36, C41, C57: 2.2u; C_0805_2012Metric_Pad1.18x1.45mm_HandSolder
C20, C27, C51: 47u; CP_EIA-7343-15_Kemet-W_Pad2.25x2.55mm_HandSolder
C21, C31, C39, C50, C53: 4.7u; C_0805_2012Metric_Pad1.18x1.45mm_HandSolder
C24, C30, C35, C38, C42: 10u; C_0805_2012Metric_Pad1.18x1.45mm_HandSolder
C25, C26: 47p; C_0805_2012Metric_Pad1.18x1.45mm_HandSolder
C33, C49: 47u; C_0805_2012Metric_Pad1.18x1.45mm_HandSolder
C40: 22u; C_0805_2012Metric_Pad1.18x1.45mm_HandSolder
C45, C47: 2.2n; C_0805_2012Metric_Pad1.18x1.45mm_HandSolder
C48: 680p; C_0805_2012Metric_Pad1.18x1.45mm_HandSolder
C55: 1u; C_0805_2012Metric_Pad1.18x1.45mm_HandSolder
C58, C59, C60: 390n; C_0805_2012Metric_Pad1.18x1.45mm_HandSolder
D1: SYS_LED; LED_D3.0mm_FlatTop
D3: CHRG_LED; LED_SMD_custom
D4: BZT52-C3V3X; Nexperia_CFP3_SOD-123W
D5: S1ABF; D_SMB
D6: MBR0520; D_SOD-123
D7, D8, D9: 1N5819HW-7-F; D_SOD-123
EXP1: Conn_01x06; 2.54x6_flat
F1: 2A; Fuse_1206_3216Metric
H1, H2, H3, H4, H5, H6, H7, H8, H9: Hole; Hole 1,6mm
J1: PROG; PinHeader_1x06_P1.27mm_Vertical
J2: USB_C_Receptacle_USB2.0; USB_C
J3: LCD_CONN; Hirose_FH12-40S-0.5SH_1x40-1MP_P0.50mm_Horizontal
J4: INT_EXP; PinHeader_2x08_P1.27mm_Vertical_SMD
J5: BATT; PinHeader_1x02_P2.54mm_Horizontal
J9: Micro_SD_Card_Det; SD-Connector
J10: SPKR; PinHeader_1x02_P1.27mm_Vertical
J11: AudioJack; 3.5 Jack
L1: 4.7uH; HCM1A4020V2
L2: 10uH; SDN0530MT100
Q1: IRLML6302; SOT-23
R1, R2, R4, R10, R12, R31, R33, R42, R43: 10k; R_0805_2012Metric_Pad1.20x1.40mm_HandSolder
R3, R5, R11: 15k; R_0805_2012Metric_Pad1.20x1.40mm_HandSolder
R6: 220; R_0805_2012Metric_Pad1.20x1.40mm_HandSolder
R7, R8: 27; R_0805_2012Metric_Pad1.20x1.40mm_HandSolder
R9, R24, R25: 470; R_0805_2012Metric_Pad1.20x1.40mm_HandSolder
R13: 100K; R_0805_2012Metric_Pad1.20x1.40mm_HandSolder
R14: 1k2 1%; R_0805_2012Metric_Pad1.20x1.40mm_HandSolder
R15, R16, R17, R18, R19, R21: 47k; R_0805_2012Metric_Pad1.20x1.40mm_HandSolder
R20: EN_5V; SolderJumper-2_P1.3mm_Open_TrianglePad1.0x1.5mm
R22: 680K; R_0805_2012Metric_Pad1.20x1.40mm_HandSolder
R23: 150K; R_0805_2012Metric_Pad1.20x1.40mm_HandSolder
R26: 13k3; R_0805_2012Metric_Pad1.20x1.40mm_HandSolder
R27: 40k2; R_0805_2012Metric_Pad1.20x1.40mm_HandSolder
R28, R29: 5.2k; R_0805_2012Metric_Pad1.20x1.40mm_HandSolder
R30: DET0; SolderJumper-2_P1.3mm_Open_TrianglePad1.0x1.5mm
R32, R35, R36: 20k; R_0805_2012Metric_Pad1.20x1.40mm_HandSolder
R34: R_Photo; LED_D5.0mm
R37: DET1; SolderJumper-2_P1.3mm_Open_TrianglePad1.0x1.5mm
R38: EN_USB; SolderJumper-2_P1.3mm_Open_TrianglePad1.0x1.5mm
R39: USB_DM; SolderJumper-2_P1.3mm_Open_TrianglePad1.0x1.5mm
R40: USB_DP; SolderJumper-2_P1.3mm_Open_TrianglePad1.0x1.5mm
R41: EN_3V3; SolderJumper-2_P1.3mm_Open_TrianglePad1.0x1.5mm
SW1: RESET; SW_SPST_RESET
SW2: BTN_A; SW_SPST_PTS645
SW3: BTN_B; SW_SPST_PTS645
SW4: BTN_UP; SW_SPST_PTS645
SW5: BTN_DOWN; SW_SPST_PTS645
SW6: BTN_LEFT; SW_SPST_PTS645
SW7: BTN_RIGHT; SW_SPST_PTS645
SW8: BTN_PWR; SW_Push_1P1T_NO_CK_KMR2_PWR
TP1: VREFF; TestPoint_Pad_D1.0mm
TP2: VUSB; TestPoint_Pad_D1.0mm
TP3: VBATT; TestPoint_Pad_D1.0mm
TP4: 3.3V; TestPoint_Pad_D1.0mm
TP5: 5V; TestPoint_Pad_D1.0mm
TP6: AUX_SW; TestPoint_Pad_D2.5mm
TP7: AUX_GND; TestPoint_Pad_D2.5mm
TP8: PD3; TestPoint_Pad_D2.5mm
TP9: PD4; TestPoint_Pad_D2.5mm
TP10: VCAP; TestPoint_Pad_D1.0mm
TP11: 3.3V; TestPoint_Pad_D2.5mm
TP12: GND; TestPoint_Pad_D2.5mm
U1, U3, U11: USBLC6; SOT-23-6_Handsoldering
U2: TLV431; TSOT-23
U4, U12: AP22802AW5-7; SOT-23-5_HandSoldering
U5: FT230XS; SSOP-16_3.9x4.9mm_P0.635mm
U7: PCM5102; TSSOP-20_4.4x6.5mm_P0.65mm
U8: NCP1529; SOT-23-5_HandSoldering
U9: LMR62014XMF; SOT-23-5_HandSoldering
U10: STM32H743ZITx; LQFP-144_20x20mm_P0.5mm
U13: LM4861; HSOP-8-1EP_3.9x4.9mm_P1.27mm_EP2.41x3.1mm
U14: STC4054; SOT-23-5_HandSoldering
Y1: 16Mhz; SMDXT224
Y2: 32.768; Crystal_SMD_6.7x1.5mm_HandSoldering

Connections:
1.2VREF: R1.1, TP1.1, U2.1 (REF), U2.3 (Anode), U10.47 (PB1)
+3V3: C1.1, C2.1, C5.1, C7.1, C9.1, C10.1, C12.1, C13.1, C14.1, C15.1, C16.1, C17.1, C18.1, C20.1, C21.1, C24.1, C27.1, C30.1, C32.1, C34.1, C35.1, C37.1, C39.1, C42.1, C44.1, C46.1, C49.1, C52.1, C53.1, C61.1, D7.2 (A), EXP1.3, J1.1, J3.6, J3.7, J3.39, J4.7, J9.4 (VDD), L1.2, R1.2, R15.2, R16.2, R17.2, R18.2, R19.2, R22.2, R30.1, R33.2, R37.1, R38.1, TP4.1, TP11.1, U1.5 (VBUS), U4.5 (IN), U5.3 (VCCIO), U5.12 (VCC), U7.1 (CPVDD), U7.8 (AVDD), U7.20 (DVDD), U10.17 (VDD), U10.30 (VDD), U10.32 (VREF+), U10.33 (VDDA), U10.39 (VDD), U10.52 (VDD), U10.62 (VDD), U10.72 (VDD), U10.84 (VDD), U10.108 (VDD), U10.121 (VDD), U10.131 (VDD), U10.143 (PDR_ON), U10.144 (VDD), U11.5 (VBUS), U12.5 (IN)
+5V: C31.1, C33.1, C48.2, C50.1, C51.1, C54.1, D6.1 (K), R27.1, R41.1, TP5.1, U8.4 (VIN), U13.6 (VDD)
+BATT: F1.2, J4.9, Q1.3 (D), R2.2, TP3.1, U14.3 (BAT)
AMB_SENS: R33.1, R34.1, U10.40 (PA4)
AUX_SWITCH: U10.1 (PE2), U12.4 (EN)
BEEPER: C58.1, U10.85 (PD14)
BTN_A: SW2.1 (A), U10.45 (PC5)
BTN_B: SW3.1 (A), U10.26 (PC0)
BTN_DOWN: SW5.1 (A), U10.29 (PC3_C)
BTN_LEFT: SW6.1 (A), U10.44 (PC4)
BTN_PWR: D4.1 (K), D9.2 (A), R12.1, U10.34 (PA0)
BTN_RIGHT: SW7.1 (A), U10.27 (PC1)
BTN_UP: SW4.1 (A), U10.28 (PC2_C)
CHRG_STAT: R10.1, R11.2, U10.36 (PA2)
EXT_IO1: U1.4 (I/02), U10.35 (PA1)
EXT_IO2: U1.6 (I/01), U10.37 (PA3)
EXT_IO3: U10.96 (PC6), U11.4 (I/02)
EXT_IO4: U10.97 (PC7), U11.6 (I/01)
FTDI_RX: U5.4 (RXD), U10.119 (PD5)
FTDI_TX: U5.1 (TXD), U10.122 (PD6)
FTDI_TXE: U5.15 (CBUS0), U10.123 (PD7)
GND: C1.2, C2.2, C3.1, C4.1, C5.2, C6.2, C7.2, C8.2, C9.2, C10.2, C11.2, C12.2, C13.2, C14.2, C15.2, C16.2, C17.2, C18.2, C19.2, C20.2, C21.2, C22.1, C23.1, C24.2, C25.2, C26.2, C27.2, C28.2, C29.2, C30.2, C31.2, C32.2, C33.2, C34.2, C35.2, C36.2, C37.2, C38.2, C39.2, C41.2, C42.2, C43.2, C44.2, C45.2, C47.2, C49.2, C50.2, C51.2, C52.2, C53.2, C54.2, C55.2, C56.2, C57.2, C61.2, D4.2 (A), EXP1.1, H1.1, H2.1, H3.1, H4.1, H5.1, H6.1, H7.1, H8.1, H9.1, J1.3, J2.A1 (GND), J2.A12 (GND), J2.B1 (GND), J2.B12 (GND), J2.S1 (SHIELD), J3.5, J3.16, J3.34, J3.35, J3.36, J3.37, J3.38, J3.40, J4.11, J5.1, J9.6 (VSS), J9.10 (SHIELD), J11.S, R3.2, R5.2, R6.1, R11.1, R13.2, R14.1, R21.2, R23.1, R26.2, R28.1, R29.1, R34.2, R42.2, SW1.1 (A), SW2.2 (B), SW3.2 (B), SW4.2 (B), SW5.2 (B), SW6.2 (B), SW7.2 (B), TP7.1, TP12.1, U1.2 (GND), U2.2 (Cathode), U3.2 (GND), U4.2 (GND), U5.5 (GND), U5.13 (GND), U7.3 (CPGND), U7.9 (AGND), U7.10 (DEMP), U7.11 (FLT), U7.16 (FMT), U7.19 (DGND), U8.2 (GND), U9.2 (GND), U10.16 (VSS), U10.31 (VSSA), U10.38 (VSS), U10.51 (VSS), U10.61 (VSS), U10.83 (VSS), U10.94 (VSS), U10.107 (VSS), U10.120 (VSS), U10.130 (VSS), U10.138 (BOOT0), U11.2 (GND), U12.2 (GND), U13.7 (GND), U14.2 (GND), Y1.3
IEXP1_P1: J4.1, U10.77 (PD8)
IEXP1_P2: J4.3, U10.78 (PD9)
IEXP1_P3: J4.5, U10.79 (PD10)
IEXP1_RX: J4.2, U10.101 (PA9)
IEXP1_TX: J4.4, U10.102 (PA10)
IEXP2_P1: J4.13, U10.80 (PD11)
IEXP2_P2: J4.15, U10.81 (PD12)
IEXP2_P8: J4.16, U10.82 (PD13)
IEXP2_RX: J4.12, U10.69 (PB10)
IEXP2_TX: J4.14, U10.70 (PB11)
ISP_SWCLK: J1.2, U10.109 (PA14)
ISP_SWDIO: J1.4, U10.105 (PA13)
ISP_TRACESWO: J1.6, U10.133 (PB3)
JACK_SENSE: J11.SN, U10.100 (PA8)
LCD_BL: C28.1, C29.1, J3.33, U4.1 (OUT)
LCD_BL_SHDN: U4.4 (EN), U10.5 (PE6)
LCD_CS: J3.9, U10.4 (PE5)
LCD_D0: J3.17, U10.10 (PF0)
LCD_D1: J3.18, U10.11 (PF1)
LCD_D2: J3.19, U10.12 (PF2)
LCD_D3: J3.20, U10.13 (PF3)
LCD_D4: J3.21, U10.14 (PF4)
LCD_D5: J3.22, U10.15 (PF5)
LCD_D6: J3.23, U10.18 (PF6)
LCD_D7: J3.24, U10.19 (PF7)
LCD_D8: J3.25, U10.20 (PF8)
LCD_D9: J3.26, U10.21 (PF9)
LCD_D10: J3.27, U10.22 (PF10)
LCD_D11: J3.28, U10.49 (PF11)
LCD_D12: J3.29, U10.50 (PF12)
LCD_D13: J3.30, U10.53 (PF13)
LCD_D14: J3.31, U10.54 (PF14)
LCD_D15: J3.32, U10.55 (PF15)
LCD_RD: J3.12, U10.59 (PE8)
LCD_RS: J3.10, U10.63 (PE10)
LCD_RST: J3.15, U10.58 (PE7)
LCD_WR: J3.11, U10.60 (PE9)
MCU_3.3V_REG_EN: D8.2 (A), U10.41 (PA5)
MCU_5V_REG_EN: R43.1, U10.64 (PE11)
MCU_USB_DM: R39.1, U10.103 (PA11)
MCU_USB_DP: R40.1, U10.104 (PA12)
unnamed: C45.1, C59.1, J11.R, J11.RN, R25.2
unnamed: C47.1, C60.1, J11.T, J11.TN, R24.2
unnamed: C58.2, R35.1
unnamed: C59.2, R32.1
unnamed: C60.2, R36.1
unnamed: D1.1 (K), R6.2
unnamed: D3.1 (K), R9.2
unnamed: D6.2 (A), L2.2, U9.1 (SW)
unnamed: C19.1, D7.1 (K), U10.6 (VBAT)
unnamed: D8.1 (K), D9.1 (K), R41.2, R42.1, U8.1 (EN)
unnamed: EXP1.2, U1.3 (I/02)
unnamed: EXP1.4, U1.1 (I/01)
unnamed: EXP1.5, U11.3 (I/02)
unnamed: EXP1.6, U11.1 (I/01)
unnamed: J2.A5 (CC1), R29.2
unnamed: J2.B5 (CC2), R28.2
unnamed: J2.A6 (D+), J2.B6 (D+), U3.3 (I/02)
unnamed: J2.A7 (D-), J2.B7 (D-), U3.1 (I/01)
unnamed: F1.1, J5.2
unnamed: J10.1, U13.8 (Vo2)
unnamed: J10.2, R31.2, U13.5 (Vo1)
unnamed: R7.1, R39.2, U3.6 (I/01)
unnamed: R8.1, R40.2, U3.4 (I/02)
unnamed: R12.2, SW8.1 (A)
unnamed: C26.1, R7.2, U5.9 (USBDM)
unnamed: C25.1, R8.2, U5.8 (USBDP)
unnamed: C40.2, U7.4 (CAPM)
unnamed: C40.1, U7.2 (CAPP)
unnamed: C38.1, C43.1, U7.18 (LDOO)
unnamed: R24.1, U7.6 (OUTL)
unnamed: R25.1, U7.7 (OUTR)
unnamed: C36.1, U7.5 (VNEG)
unnamed: C46.2, R22.1, R23.2, U8.5 (FB)
unnamed: L1.1, U8.3 (SW)
unnamed: R13.1, R20.2, R21.1, R43.2, U9.4 (EN)
unnamed: C48.1, R26.1, R27.2, U9.3 (FB)
unnamed: C22.2, U10.8 (PC14), Y2.1
unnamed: C23.2, U10.9 (PC15), Y2.2
unnamed: TP8.1, U10.114 (PD0)
unnamed: TP9.1, U10.115 (PD1)
unnamed: R30.2, U10.124 (PG9)
unnamed: R37.2, U10.125 (PG10)
unnamed: C3.2, U10.23 (PH0), Y1.2
unnamed: C4.2, U10.24 (PH1), Y1.1
unnamed: C6.1, TP10.1, U10.71 (VCAP1)
unnamed: C8.1, U10.106 (VCAP2)
unnamed: R38.2, U10.95 (VDD33_USB)
unnamed: C56.1, C57.1, TP6.1, U12.1 (OUT)
unnamed: C55.1, U13.2 (BYPASS), U13.3 (+IN)
unnamed: R9.1, R10.2, U14.1 (CHRG)
unnamed: R14.2, U14.5 (PROG)
PCM_CK: U7.13 (BCK), U10.74 (PB13)
PCM_MUTE: U7.17 (XSMT), U10.75 (PB14)
PCM_SD: U7.14 (DIN), U10.76 (PB15)
PCM_WS: U7.15 (LRCK), U10.73 (PB12)
RESET: C11.1, J1.5, SW1.2 (B), U10.25 (NRST)
SD_CLK: J9.5 (CLK), U10.113 (PC12)
SD_CMD: J9.3 (CMD), R17.1, U10.116 (PD2)
SD_D0: J9.7 (DAT0), R18.1, U10.98 (PC8)
SD_D1: J9.8 (DAT1), R19.1, U10.99 (PC9)
SD_D2: J9.1 (DAT2), R15.1, U10.111 (PC10)
SD_D3: J9.2 (DAT3/CD), R16.1, U10.112 (PC11)
SD_DETECT: J9.9 (DET_B), U10.110 (PA15)
SPI4_MISO: J4.8, U10.66 (PE13)
SPI4_MOSI: J4.10, U10.67 (PE14)
SPI4_SCK: J4.6, U10.65 (PE12)
SPKR_PCM: R31.1, R32.2, R35.2, R36.2, U13.4 (-IN)
SPKR_SHDN: U10.86 (PD15), U13.1 (SHDN)
SYS_LED: D1.2 (A), U10.87 (PG2)
TS_ADC1: J3.1, U10.42 (PA6)
TS_ADC2: J3.2, U10.43 (PA7)
TS_P1: J3.3, U10.56 (PG0)
TS_P2: J3.4, U10.57 (PG1)
VBATT_SENSE: R2.1, R3.1, U10.46 (PB0)
VBUS: D3.2 (A), D5.2 (A), J2.A4 (VBUS), J2.A9 (VBUS), J2.B4 (VBUS), J2.B9 (VBUS), Q1.1 (G), R4.2, TP2.1, U3.5 (VBUS), U14.4 (VCC)
VBUS_SENSE: R4.1, R5.1, U10.137 (PB7)
VD: C41.1, D5.1 (K), L2.1, Q1.2 (S), R20.1, SW8.2 (B), U9.5 (VIN)

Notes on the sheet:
MCU Misc.
Battery voltage
USART1
*I2S2
Internal Expansion 1
Beta 1
40k2 will give about 4.95V output voltage and 93uA divider current orig C=660, but value was out of stock..
Internal Expansion
3.3 - 2.7V
USART2
IM0 IM1 IM2
USB + FTDI
SD Card
System status LED
USART3
PCM Audio
USART8
USART4
5 - 2.7V
Vref
PH0 - OSC_IN PH1 - OSC_OUT
Switching power
Rev Detect: 0: unpopulated
note: 330pF
2026-04-19
LCD connector
This diode for 500mA avg only!
USART6
External Expansion
TIM4_CH3
TIM15_CH2
USB Vbus
PC14 - OSC32_IN PC15 - OSC32_OUT
USB_OTG
Battery charging

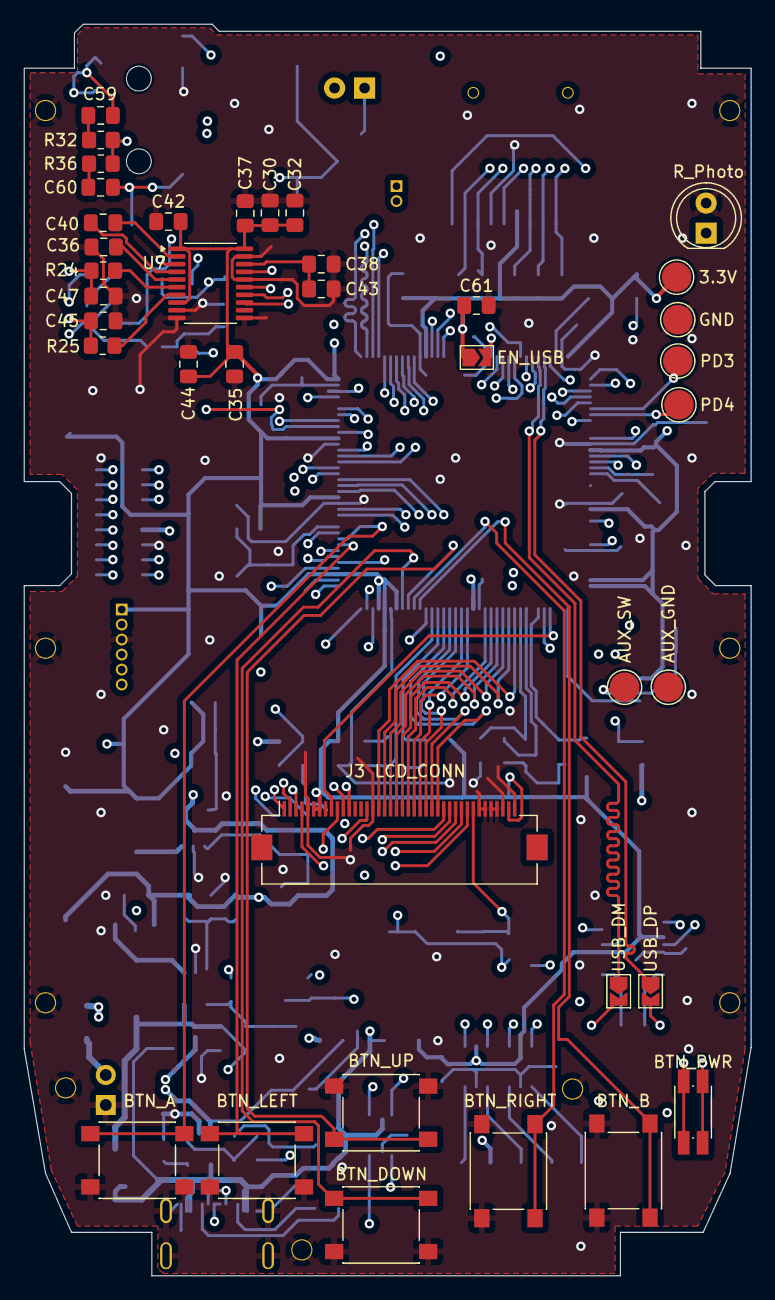
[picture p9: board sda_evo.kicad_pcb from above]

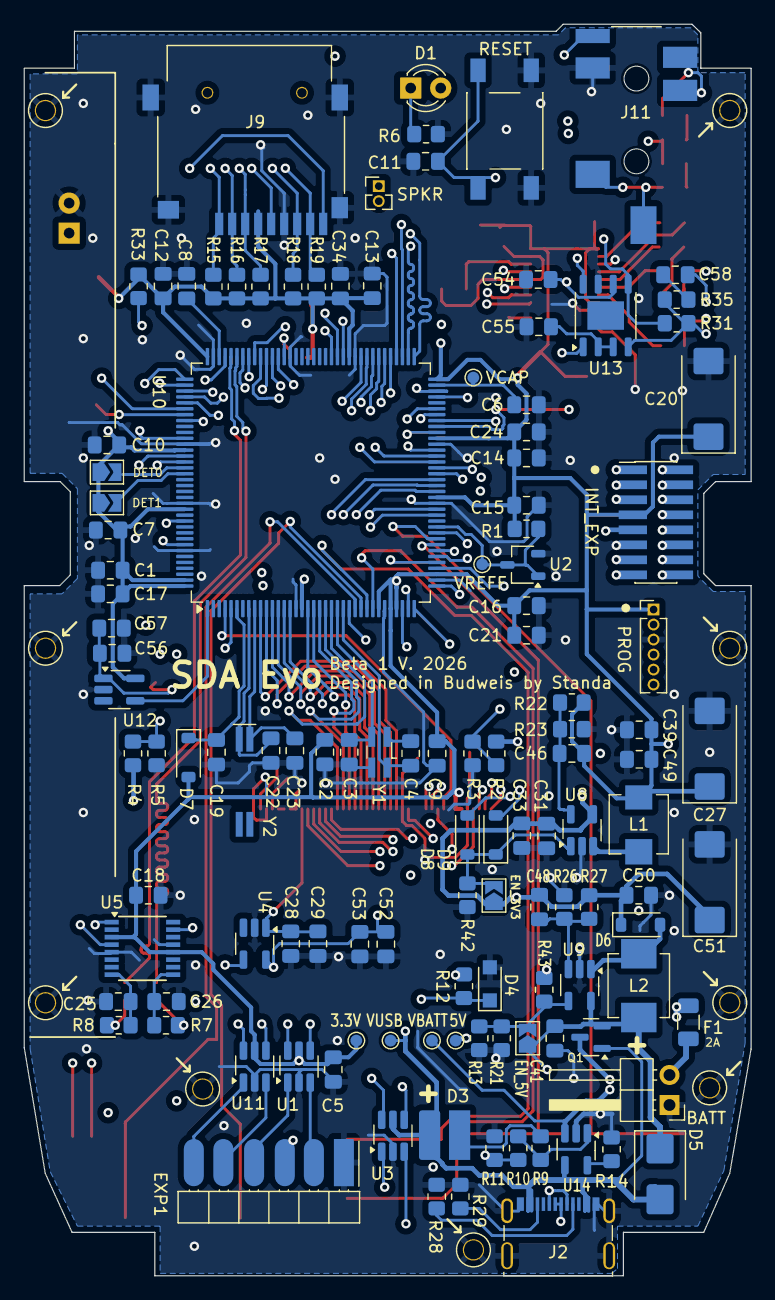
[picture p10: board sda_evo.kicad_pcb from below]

Board: 4 copper layers, 61.5 x 105.9 mm, 169 parts (131 on the bottom side), 141 nets.

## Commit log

2024-03-28 Adaded part mockups. PCB is nearly finished.
    [sda_evo.kicad_pcb, sda_evo.kicad_sch]
2024-03-29 i2s vias lenght matched
    [sda_evo.kicad_pcb]
2024-03-29 3.5 jack moved a bit, added few holes to the casing
    [sda_evo.kicad_pcb]
2024-05-03 PCB: footprints adjusted
    [sda_evo.kicad_pcb, sda_evo.kicad_sch]
2025-06-20 did some stuff
    [sda_evo-B_Cu.gbr, sda_evo-B_Mask.gbr, sda_evo-B_Silkscreen.gbr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]
2025-06-20 pcb: dac turned around
    [sda_evo.kicad_pcb]
2025-12-08 repo cleanup, board twaked
    [sda_evo-BOM.csv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]
2025-12-08 cap moved out of te way
    [sda_evo.kicad_pcb, sda_evo.step]
2025-12-16 case cleanup, port cover finalized
2025-12-16 datasheets cleanup, pcb finalized
    [sda_evo-BOM.ods, sda_evo.kicad_pcb, sda_evo.kicad_sch]
2025-12-18 Fab layers cleaned up
    [sda_evo.kicad_pcb]
2026-04-18 commit before beta1
    [sda_evo-BOM.ods, sda_evo.kicad_pcb, sda_evo.kicad_sch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]
2026-04-22 feat: fixed b0 problems, pushed to b1
    [sda_evo.kicad_pcb, sda_evo.kicad_sch]
2026-05-25 PCB updates for B1
    [sda_evo-BOM-B1.csv, sda_evo-BOM-B1.ods, sda_evo.kicad_pcb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]
2026-05-25 PCB and case files updated
    [sda_evo.stl]
2026-07-07 feat: beta1
    [SDA_Evo.fcstd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]
